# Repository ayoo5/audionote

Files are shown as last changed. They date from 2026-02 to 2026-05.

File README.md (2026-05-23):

<div align="center">
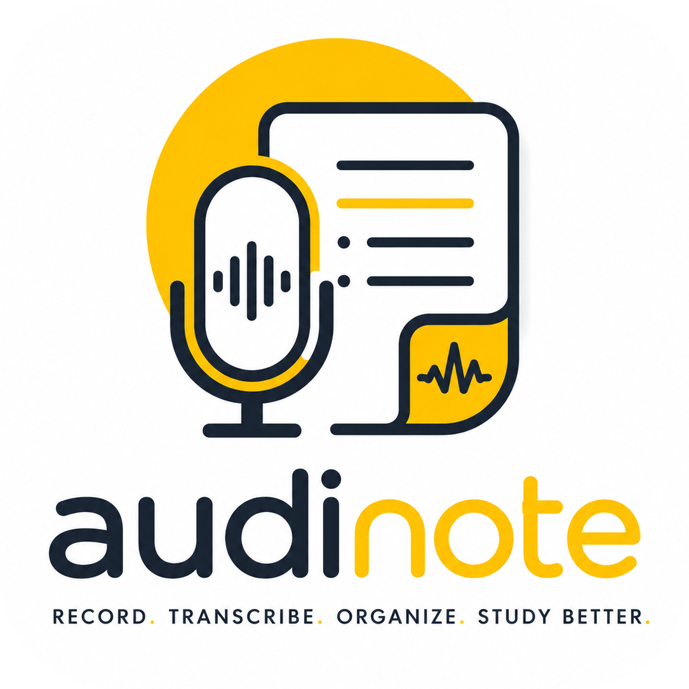
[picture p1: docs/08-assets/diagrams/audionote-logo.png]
Audionote Logo
  
  <br>
  <h3 style="margin-bottom: 0; line-height: 1;"><strong>Audionote</strong></h3>
  
  ESP32-powered asynchronous lecture transcription and archival system with automated cloud upload, cloud-based speech-to-text processing, and structured Google Shared Drive organization.
</div>

<div align="center">

| Initial Build Setup | Final Enclosed Build <br> (not the 3D printed enclosure) |
| :---: | :---: |
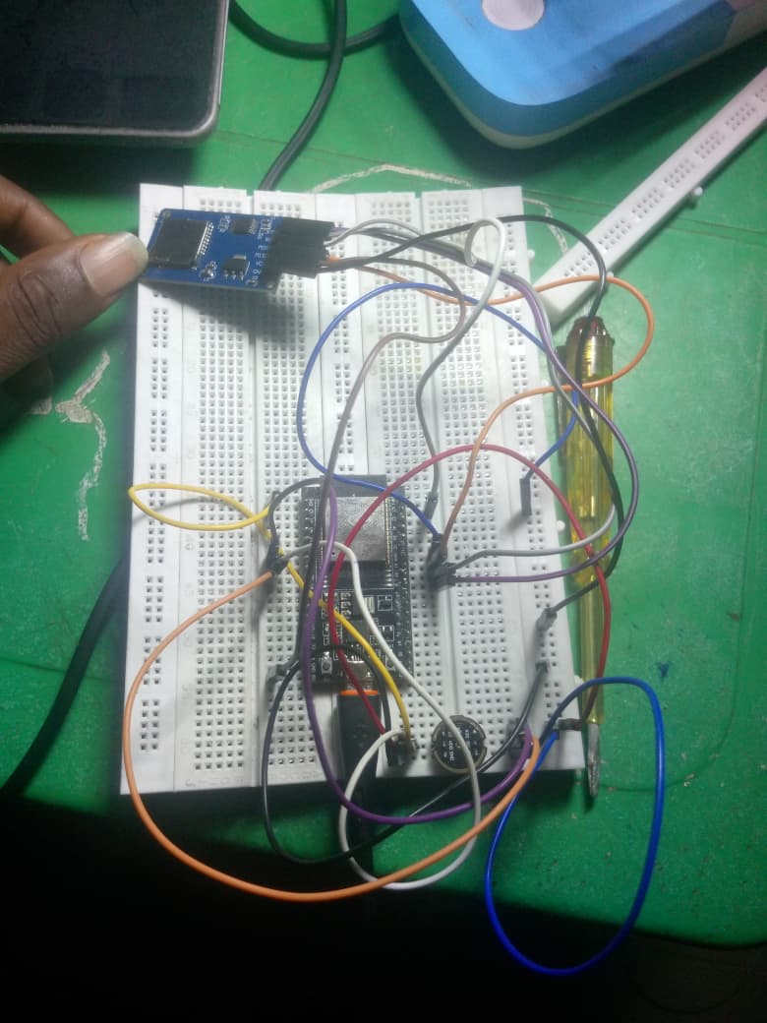
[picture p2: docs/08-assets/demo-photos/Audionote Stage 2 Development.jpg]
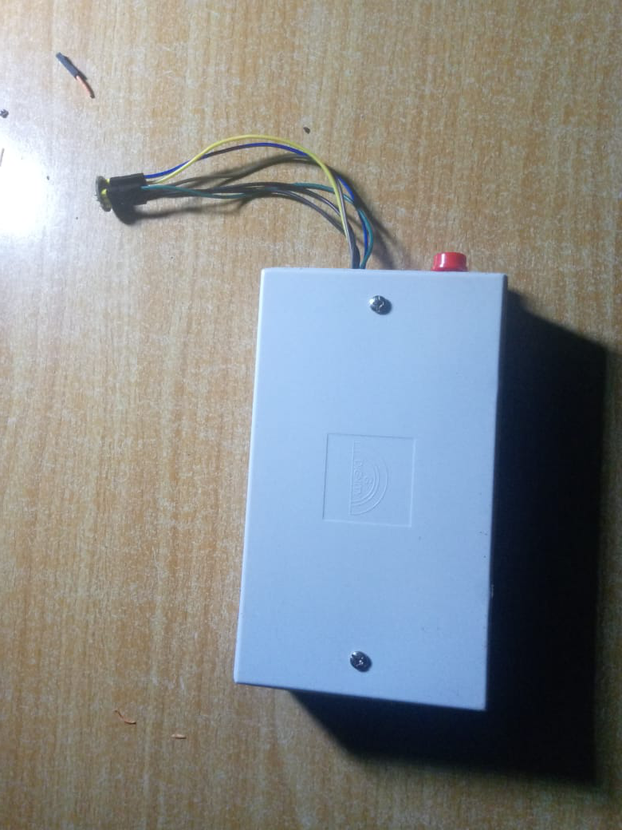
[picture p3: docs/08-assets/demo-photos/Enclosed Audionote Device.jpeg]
|  |  |

</div>

# Overview

Audionote is a low-cost embedded lecture transcription and archival platform designed for educational environments with unreliable connectivity and limited infrastructure.

The system captures lecture audio using an ESP32-based embedded device, stores recordings locally on an SD card, uploads audio recordings to a cloud backend in chunks once Wi-Fi becomes available, automatically transcribes the recordings using cloud speech-to-text services, and archives both the audio and transcript files in an organized Google Shared Drive structure.

The project was developed as part of the design and implementation of an asynchronous lecture transcription and archive device system for tertiary educational environments.

# Why Audionote Exists

Traditional note-taking methods are often incomplete, inconsistent, and inaccessible to many students.

In many developing educational environments, real-time transcription systems are impractical due to:

* unstable internet connectivity,
* high cloud streaming costs,
* limited embedded processing power,
* and infrastructure limitations.

Audionote addresses these constraints through an asynchronous edge-to-cloud architecture that prioritizes:

* reliable lecture capture,
* cloud-assisted transcription,
* structured archival,
* and educational accessibility.

The system is particularly useful for:

* students reviewing lecture content,
* accessibility support,
* institutional lecture archiving,
* asynchronous learning,
* and educational content preservation.

# Core Features

## Embedded Systems Features

* ESP32-based audio acquisition pipeline
* INMP441 I2S MEMS microphone integration
* WAV audio recording and formatting
* Local SD card audio buffering and storage
* Push-button lecture recording control
* Chunked upload architecture for large audio recordings
* Portable low-power embedded system design
* Recoverable upload workflow
* Hardware modularity for future PCB migration

## Cloud Features

* Secure signed upload URL generation
* Chunked cloud upload pipeline
* Google Cloud Run backend services
* Automated speech-to-text transcription
* Automatic Google Shared Drive organization
* Cloud-based lecture archival system
* Structured folder organization by course and level
* Cloud storage redundancy

## Systems Engineering Features

* Distributed edge-to-cloud architecture
* Asynchronous post-recording transcription
* Local-first fault-tolerant workflow
* Modular firmware and backend separation
* Recoverable upload session handling
* Automated backend processing pipeline
* Persistent local recording backup
* Scalable backend infrastructure

# System Architecture

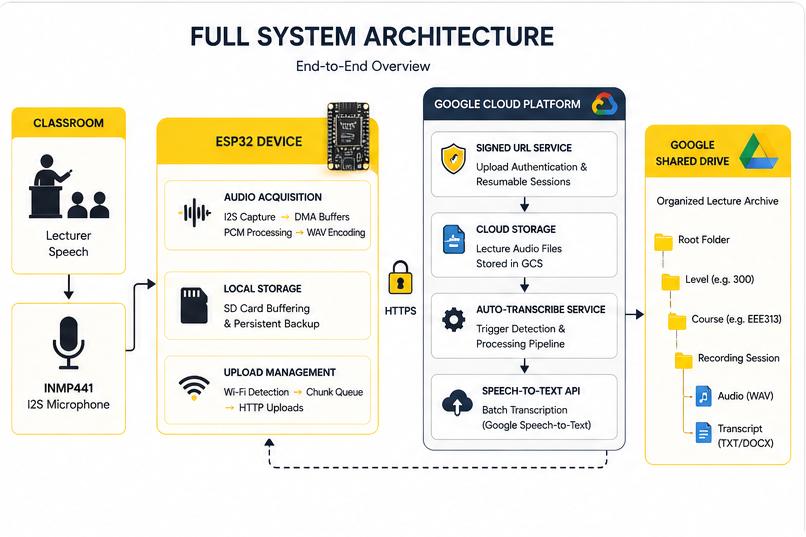
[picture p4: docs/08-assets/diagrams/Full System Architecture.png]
System architecture


## End-to-End Operational Workflow

```text
1. Lecturer powers the device
2. ESP32 initializes peripherals
3. Audio is captured from the INMP441 microphone
4. Audio is encoded into WAV format
5. Recording is stored locally on SD card
6. Recording session stops
7. Wi-Fi connection is detected
8. Audio file uploads in chunks to backend
9. Cloud backend processes uploaded recording
10. Speech-to-text transcription is generated
11. Audio and transcript are archived automatically
12. Files become accessible through Shared Drive
```

# Engineering Results Snapshot

Audionote was experimentally evaluated under realistic classroom and network conditions using an ESP32-based asynchronous lecture transcription architecture.

The system demonstrated stable operation across:
- extended recording sessions,
- cloud-based asynchronous transcription,
- structured archival workflows,
- and resumable upload recovery scenarios.

---

## Key Experimental Results

| Metric | Observation |
|---|---|
| Audio Sampling Rate | Stable 16 kHz PCM acquisition |
| Transcription Architecture | Asynchronous cloud-based pipeline |
| Average WER | ~35% under classroom conditions |
| Transcript Completeness | Typically 95–105% |
| Storage Efficiency | ~1.9–2.0 MB/min |
| Processing Throughput | Up to 2–5× real-time under favorable conditions |
| Button Reliability | >93% consistency across ~100 trials |
| File Organization | Structured timestamped archival successful |
| Upload Reliability | Improved using resumable uploads |
| System Stability | Stable extended operation observed |

---

## Key Engineering Observations

- Cloud-based ASR improved transcription quality compared to fully edge-based processing.
- Asynchronous transcription significantly reduced firmware complexity and memory pressure on the ESP32.
- Resumable uploads improved fault tolerance during unstable network conditions.
- Structured cloud archival improved retrieval and scalability.
- Signal integrity was strongly influenced by microphone cable length and solder quality.

---

## Notable System Trade-offs

| Design Choice | Trade-off |
|---|---|
| Cloud ASR | Better accuracy but network dependency |
| Asynchronous Processing | Better stability but no real-time feedback |
| ESP32-Based Design | Low-cost but resource constrained |
| Wearable Form Factor | Better audio capture but tighter hardware integration |

---

## Reference

Detailed experimental evaluation, metrics, formulas, and engineering analysis are documented in:

→ [Engineering Analysis](docs/06-analysis/engineering-analysis.md)

# Repository Structure

```text
lecture-transcription-iot/
│
├── firmware/          # ESP32 firmware source code
├── backend/           # Cloud backend services
├── hardware/          # Schematics, wiring, enclosure files
├── docs/              # Full technical documentation
├── media/             # Demo assets and presentation materials
└── README.md          # You are here 🙂
```

# Quick Start Roadmap

This project is organized as a guided end-to-end engineering workflow.

The recommended implementation path is:

```text
Firmware Environment Setup
        ↓
ESP32 Firmware Upload
        ↓
Hardware Component Acquisition
        ↓
Incremental Hardware Assembly & Testing
        ↓
Power System Integration
        ↓
Backend Deployment (Google Cloud)
        ↓
Shared Drive & Domain Setup
        ↓
Final System Integration
        ↓
Enclosure & Portability Upgrades
        ↓
Testing, Optimization & Contributions
```

The sections below guide you through each stage of the build process in the recommended engineering order.

## Stage 1 — Firmware Development Environment

The firmware is responsible for:

* audio acquisition,
* WAV formatting,
* SD card storage,
* chunked upload handling,
* Wi-Fi connectivity,
* and upload session management.

## Firmware Pipeline

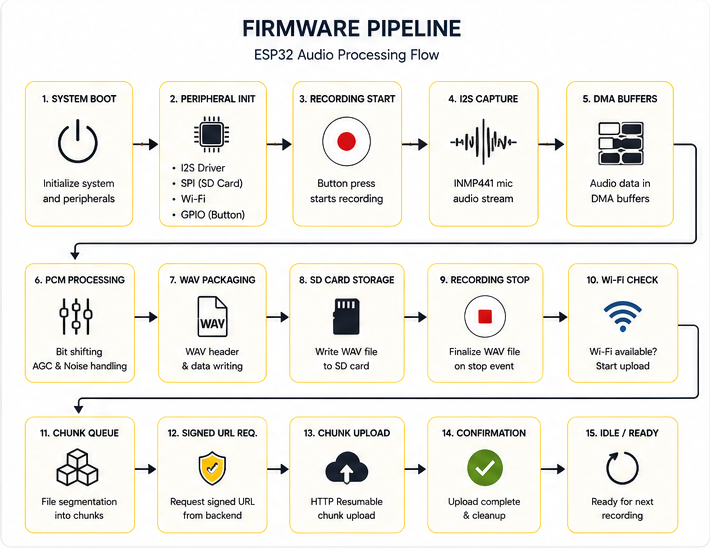
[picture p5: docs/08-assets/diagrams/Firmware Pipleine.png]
Firmware Pipeline


Before assembling the hardware, first prepare the ESP32 firmware environment and confirm that firmware can be successfully uploaded to the board.

This stage includes:

- Installing Arduino IDE
- Installing the ESP32 board package
- Installing required firmware libraries
- Configuring the firmware project
- Verifying serial communication
- Uploading firmware to the ESP32

Continue to:

→ [Firmware Overview](docs/03-firmware/firmware-overview.md)

And then:

→ [Firmware Setup](docs/03-firmware/esp32-setup.md)

## Stage 2 — Hardware Components & BOM

After validating the firmware environment, acquire the required hardware components and development materials.

This section includes:

- Main embedded components
- Power system components
- Wiring materials
- Development accessories
- Optional enclosure materials

Continue to:

→ [Bill of Materials](docs/02-hardware/bill-of-materials.md)

## Stage 3 — Hardware Assembly & Incremental Testing

The hardware integration process is intentionally broken into incremental validation stages to simplify debugging and subsystem verification.

### Hardware Block Diagram

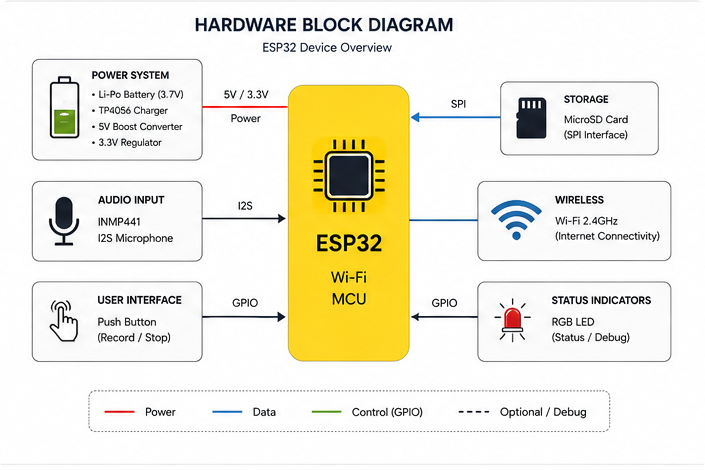
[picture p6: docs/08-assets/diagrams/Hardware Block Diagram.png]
Hardware Block Diagram


This stage includes:

- ESP32 basic validation
- INMP441 microphone integration
- SD card module integration
- Audio recording verification
- Chunk upload validation
- Hardware troubleshooting checkpoints

Continue to:

→ [Hardware Assembly Guide](docs/02-hardware/assembly-guide.md)

## Stage 4 — Power System Integration

After validating the core audio and upload system, integrate the portable power subsystem.

This stage includes:

- Battery integration
- TP4056 charging module setup
- MT3608 voltage regulation
- Power stability testing
- Brownout prevention
- Safe portable deployment

Continue to:

→ [Power System Documentation](docs/02-hardware/power-system.md)

## Stage 5 — Backend Infrastructure Setup

Deploy the Google Cloud backend services required for upload orchestration and transcription.

### Backend Pipeline

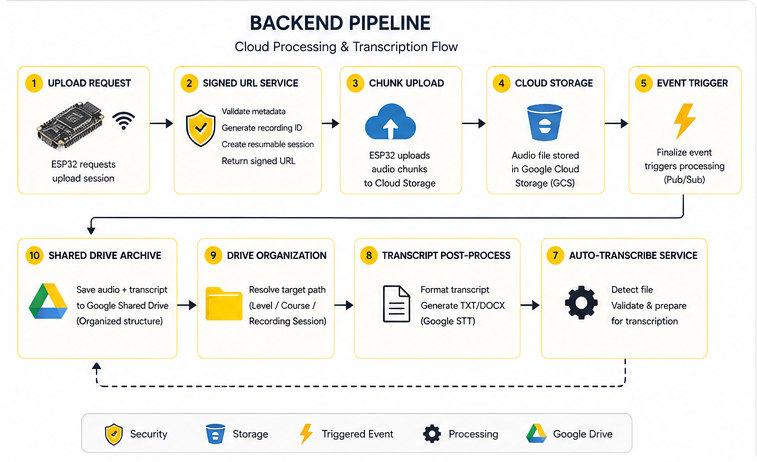
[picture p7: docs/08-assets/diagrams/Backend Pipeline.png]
Backend Pipeline


This stage includes:

- Google Cloud project setup
- Cloud Run deployment
- Signed URL service setup
- Auto-transcription service setup
- Storage bucket configuration
- IAM permissions configuration

Continue to:

→ [Backend Overview](docs/04-backend/backend-overview.md)

## Backend Deployment

Choose your preferred deployment workflow:

### Option 1 — GUI-Based Deployment (Recommended for Beginners)

Step-by-step Google Cloud Console deployment using mostly the graphical interface.

→ [GUI Backend Deployment Guide](docs/04-backend/deployment-gui-based.md)

---

### Option 2 — CLI-Based Deployment

Terminal-based deployment using gcloud and Cloud Shell.

→ [CLI Backend Deployment Guide](docs/04-backend/deployment-guide.md)

## Stage 6 — Shared Drive & Domain Configuration

Configure the shared archival environment for automated transcript organization.

This stage includes:

- Google Workspace setup
- Shared Drive creation
- Domain configuration
- Drive API integration
- Folder structure automation

Continue to:

→ [Shared Drive Setup Guide](docs/04-backend/shared-drive-integration.md)

## Stage 7 — Final Integration & Enclosure Assembly

Combine all validated subsystems into the final portable deployment configuration.

### Final Prototype

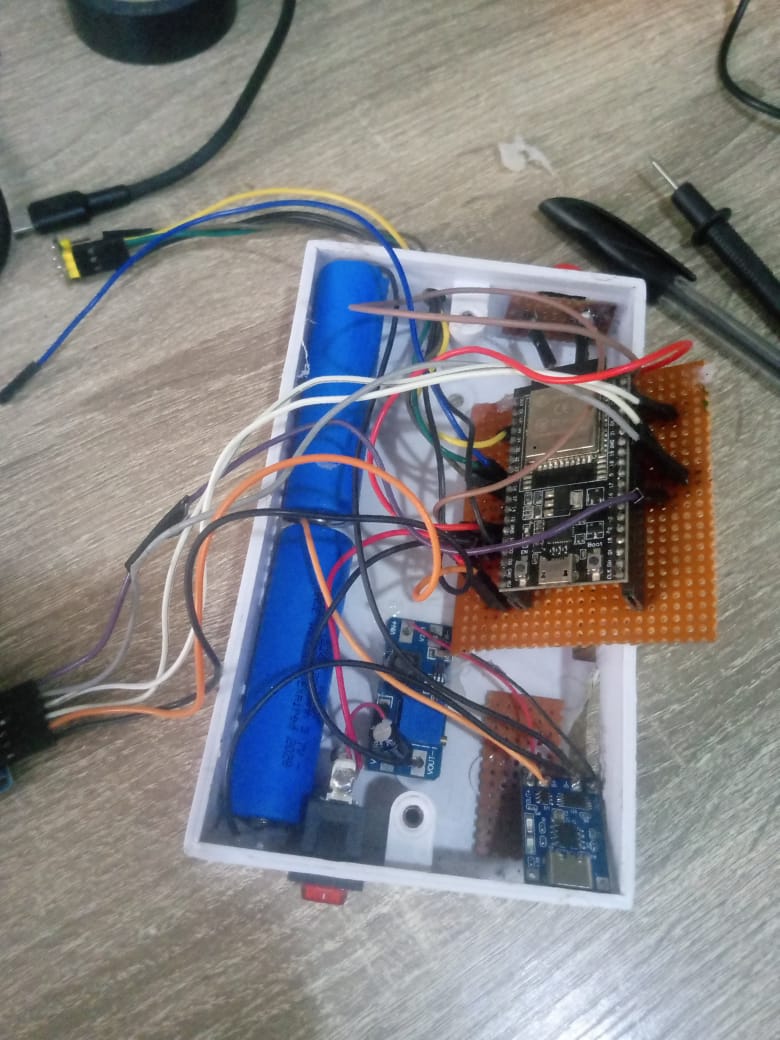
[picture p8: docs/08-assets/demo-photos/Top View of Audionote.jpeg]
Final Prototype


This stage includes:

- Internal component mounting
- Cable management
- [Enclosure assembly](/hardware/enclosure) designed by a friend, [Elias](https://github.com/buildwithelias)
- Thermal considerations
- Wearable mounting system integration
- Final operational testing

Continue to:

→ [Final System Integration](docs/05-system-integration/full-system-integration.md)

## Stage 8 — Optional Upgrades & Contributions

Audionote is designed as a modular and extensible embedded systems platform.

Optional enhancements include:

- 3D printed enclosure upgrades
- Alternative speech-to-text models
- OTA firmware updates
- Noise suppression pipelines
- Custom PCB development
- Mobile configuration systems

Contributors and builders are encouraged to:

- share their builds,
- submit pull requests,
- experiment with backend architectures,
- improve subsystem reliability,
- and extend the platform into new educational or embedded use cases.

Continue to:

→ [Contributing Guide](CONTRIBUTING.md)

## Stage 9 — Engineering Analysis & System Evaluation

This repository includes measured engineering analysis and implementation tradeoff documentation intended to support:

- reproducibility,
- system evaluation,
- embedded optimization,
- and academic engineering analysis.

Included analysis areas:

- memory usage measurements
- upload latency analysis
- storage utilization analysis
- chunk upload optimization
- backend processing latency
- power consumption measurements
- reliability observations
- embedded systems tradeoffs

These documents are especially useful for:

- embedded systems learners,
- engineering students,
- firmware developers,
- and contributors seeking to optimize or extend the system.

Continue to:

→ [Engineering Analysis](docs/06-analysis/build-analysis.md)

## Stage 10 — Troubleshooting & Debugging

Due to the multi-domain nature of the project (embedded systems, cloud infrastructure, storage systems, networking, and power electronics), troubleshooting documentation is provided throughout the repository.

Common troubleshooting areas include:

- ESP32 flashing failures
- SD card mounting issues
- I2S microphone configuration problems
- distorted or clipped audio
- Wi-Fi upload instability
- Cloud authentication failures
- Speech-to-text API errors
- power instability and brownouts
- backend deployment failures

The troubleshooting documentation also includes:

- incremental validation checkpoints,
- expected subsystem outputs,
- debugging methodology,
- and common failure recovery procedures.

---

# Contact & Project Updates

If you recreate, improve, or extend Audionote, feel free to share your build, feedback, or ideas.

I’d genuinely love to see:
- recreated builds,
- backend improvements,
- enclosure redesigns,
- PCB versions,
- and transcription experiments.

## Contact

- Email: krestonayo5@gmail.com
- LinkedIn: https://linkedin.com/in/chrisayo/
- GitHub: https://github.com/Ayoo5

## Sharing Your Build

If you share your recreation publicly, consider tagging:
- #AudionoteProject
- #ESP32
- #EmbeddedSystems
- my social media handles. (Just search "Christopher Ayomide Popoola" to find them.)

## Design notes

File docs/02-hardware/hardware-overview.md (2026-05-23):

# Hardware Overview

This document explains the physical architecture, subsystem design, and engineering considerations behind the Audionote hardware system.

Hardware Block Diagram

The hardware layer is responsible for:

* audio acquisition,
* local storage,
* portable power delivery,
* user interaction,
* and embedded system deployment.

The Audionote hardware architecture was designed to balance:

* affordability,
* portability,
* reproducibility,
* and practical engineering constraints.

---

# Hardware System Responsibilities

The hardware system performs several major functions:

| Subsystem | Purpose |
| --- | --- |
| Audio Capture System | Lecture recording |
| Embedded Processing System | Device control |
| Local Storage System | WAV file storage |
| Power Management System | Portable operation |
| User Input System | Recording control |
| Enclosure System | Mechanical protection |

---

# High-Level Hardware Architecture

```text id="n9lh6j"
Lecturer Audio
        ↓
INMP441 Microphone
        ↓
ESP32 Processing System
        ↓
MicroSD Storage
        ↓
Power Management System
        ↓
Cloud Upload Infrastructure
```

---

# Hardware Design Philosophy

The hardware architecture prioritizes:

| Goal | Reason |
| --- | --- |
| Low Cost | Accessibility |
| Modularity | Easier debugging |
| Portability | Real-world usability |
| Simplicity | Reproducibility |
| Cloud Integration | Scalability |

---

# Hardware Architecture Overview

The system combines:

* embedded processing,
* digital audio acquisition,
* removable storage,
* battery operation,
* and wireless networking.

---

# Core Hardware Components

| Component | Role |
| --- | --- |
| ESP32 DevKitC  | Main controller |
| INMP441 | Digital MEMS microphone |
| MicroSD Module | Audio storage |
| TP4056 | Battery charging |
| MT3608 | Voltage boosting |
| Li-ion Battery | Portable power |
| Push Button | Recording control |

---

# Main Processing System

The primary embedded controller used is:

```text id="sjvjlwm"
ESP32-WROOM-32D DevKitC
```

The ESP32 manages:

* audio sampling,
* file generation,
* SD card access,
* Wi-Fi communication,
* and upload orchestration.

---

# Why the ESP32 Was Selected

The ESP32 was selected because it provides:

* integrated Wi-Fi,
* native I2S support,
* strong embedded performance,
* and wide ecosystem support.

---

# ESP32 Advantages

| Feature | Benefit |
| --- | --- |
| Wi-Fi | Cloud uploads |
| I2S Peripheral | Digital microphone support |
| Dual-Core MCU | Better task handling |
| GPIO Availability | Peripheral integration |
| Low Cost | Accessibility |

---

# ESP32 Documentation

* [ESP32 Documentation](https://docs.espressif.com/projects/esp-idf/en/latest/esp32/?utm_source=chatgpt.com)

---

# Audio Capture System

Audionote uses:

* the INMP441 digital MEMS microphone

for lecture audio acquisition.

The microphone interfaces with the ESP32 using:

* the I2S digital audio protocol.

---

# Why the INMP441 Was Chosen

The INMP441 was selected because it:

* simplifies digital audio acquisition,
* improves signal quality,
* and integrates well with ESP32 I2S peripherals.

---

# Audio Capture Pipeline

```text id="iyqbjlwm"
Lecturer Speech
        ↓
INMP441 MEMS Microphone
        ↓
Digital I2S Audio Stream
        ↓
ESP32 Audio Buffer
        ↓
WAV File Generation
```

---

# INMP441 Documentation

* [INMP441 Datasheet](https://invensense.tdk.com/products/digital/inmp441/?utm_source=chatgpt.com)

---

# Storage System

The system uses:

* a MicroSD card module

for local WAV file storage.

This allows:

* offline recording,
* asynchronous uploads,
* and recording persistence.

---

# Storage Workflow

```text id="xjlwm1"
Audio Recording
        ↓
WAV File Generation
        ↓
MicroSD Storage
        ↓
Upload Queue
```

---

# Why Local Storage Was Important

Without local storage:

* network instability could interrupt recordings,
* upload failures could result in data loss,
* and the device would become less reliable.

Local storage improves:

* reliability,
* fault tolerance,
* and scalability.

---

# Power System Overview

Audionote was designed as a:

* portable battery-powered embedded device.

The power subsystem includes:

* rechargeable lithium-ion batteries,
* charging circuitry,
* voltage regulation,
* and power stabilization.

---

# Power Architecture

```text id="8q2jlwm"
Li-ion Battery
        ↓
TP4056 Charging Module
        ↓
MT3608 Boost Converter
        ↓
ESP32 + Peripheral Systems
```

---

# Why Battery Power Was Chosen

Battery operation enables:

* portability,
* wearable deployment,
* classroom flexibility,
* and independent operation.

---

# Power System Components

| Component | Purpose |
| --- | --- |
| Li-ion Battery | Portable energy source |
| TP4056 | Safe charging |
| MT3608 | Voltage boosting |
| Capacitor | Power stabilization |

---

# Power Stability Considerations

The ESP32 can experience:

* sudden current spikes,
* Wi-Fi transmission surges,
* and transient instability.

To improve stability:

* a 470uF capacitor was added across the power rails.

---

# Capacitor Placement

The capacitor should be connected:

* between VCC and GND,
* near the ESP32 power input.

This helps:

* reduce voltage dips,
* improve stability,
* and reduce unexpected resets.

---

# Recommended Capacitor Orientation

```text id="sjlwm2"
Capacitor (+) → VCC
Capacitor (-) → GND
```

---

# User Interaction System

A push button is used for:

* recording control,
* user interaction,
* and workflow management.

---

# Button Workflow

```text id="jlwm3r"
Button Press
        ↓
Recording Starts
        ↓
Button Press
        ↓
Recording Stops
```

---

# Mechanical Design Philosophy

The enclosure design prioritizes:

* portability,
* durability,
* accessibility,
* and iterative prototyping.

---

# Initial Prototype Enclosure

The initial prototype utilized:

* a double socket pattress enclosure.

This allowed:

* rapid prototyping,
* easier drilling,
* and faster iteration.

---

# Optional Final Enclosure

A dedicated:

* 3D printable enclosure

can also be used for:

* cleaner assembly,
* improved portability,
* and professional presentation.

---

# Enclosure Resources

→ [3D Models](/hardware/enclosure)

---

# Wearable Deployment Concept

The device can optionally integrate:

* Velcro straps,
* buckle systems,
* and soft material mounting solutions

for wearable lecture recording deployment.

---

# Example Deployment Concept

```text id="jlwm4p"
Lecturer Waist Strap
        ↓
Portable Recording Unit
        ↓
Wearable Lecture Capture
```

---

# Wiring & Signal Integrity Considerations

Signal quality can be affected by:

* long wire lengths,
* poor solder joints,
* loose grounds,
* and unstable power delivery.

---

# Recommended Hardware Practices

| Practice | Why It Helps |
| --- | --- |
| Short microphone wires | Better signal integrity |
| Proper solder joints | Reliability |
| Heat shrink insulation | Safety |
| Stable grounds | Reduced noise |
| Power rail decoupling  | Better stability |

---

# Hardware Validation Workflow

Recommended incremental validation strategy:

```text id="jlwm5q"
Validate Power Rails
        ↓
Validate ESP32 Boot
        ↓
Validate I2S Microphone
        ↓
Validate SD Card
        ↓
Validate Recording
        ↓
Validate Upload
```

This significantly simplifies debugging.

---

# Recommended Debugging Tools

| Tool | Purpose |
| --- | --- |
| Multimeter | Voltage verification |
| Arduino Serial Monitor | Firmware debugging |
| SD Card Reader | File inspection |
| USB Power Meter | Power analysis |

---

# Important Engineering Note

The hardware layer directly interfaces with:

* timing-sensitive audio systems,
* embedded storage systems,
* battery-powered circuitry,
* and wireless communication hardware.

Because of this:

* wiring quality,
* soldering consistency,
* power stability,
* and subsystem isolation

strongly influence overall system reliability.

---

# Hardware Engineering Trade-offs

| Design Choice | Trade-off |
| --- | --- |
| ESP32 Platform | Affordable but resource constrained |
| WAV Storage | Better STT quality but larger files |
| Battery Operation | Portable but power-sensitive |
| Modular Wiring | Easier debugging but bulkier assembly |

---

# Recommended Future Hardware Improvements

Potential future upgrades include:

| Upgrade | Purpose |
| --- | --- |
| Custom PCB | Cleaner integration |
| Better MEMS Microphones | Improved audio quality  |
| Battery Monitoring IC | Power analytics |
| Dedicated Audio Codec | Improved signal quality |
| Compact Enclosure | Better portability |

---

# Hardware Engineering Takeaways

The Audionote hardware architecture demonstrates practical integration between:

* embedded electronics,
* digital audio systems,
* portable power systems,
* and cloud-connected embedded workflows.

The system intentionally balances:

* affordability,
* engineering accessibility,
* modularity,
* and practical deployment constraints.

---

# Related Documentation

## Hardware Assembly Guide

→ [Hardware Assembly Guide](assembly-guide.md)

## Power System Guide

→ [Power System Guide](power-system.md)

## Firmware Overview

→ [Firmware Overview](../01-firmware/firmware-overview.md)

## Full System Integration Guide

→ [Full System Integration Guide](../05-system-integration/full-system-integration.md)

---

# Additional Resources

## ESP32 Documentation

* [ESP32 Documentation](https://docs.espressif.com/projects/esp-idf/en/latest/esp32/?utm_source=chatgpt.com)

## Arduino IDE Documentation

* [Arduino IDE Documentation](https://docs.arduino.cc/software/ide-v2?utm_source=chatgpt.com)

## INMP441 Datasheet

* [INMP441 Datasheet](https://invensense.tdk.com/products/digital/inmp441/?utm_source=chatgpt.com)

## TP4056 Reference

* [TP4056 Datasheet Reference](https://www.datasheet-pdf.info/entry/TP4056?utm_source=chatgpt.com)

## MT3608 Reference

* [MT3608 Reference Documentation](https://www.sunrom.com/download/327.pdf?utm_source=chatgpt.com)

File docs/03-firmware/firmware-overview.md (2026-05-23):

# Firmware Overview

This document explains the architecture, operational flow, and engineering decisions behind the Audionote firmware system.

Firmware Pipeline

The firmware is responsible for:

* audio acquisition,
* WAV file generation,
* SD card storage,
* wireless communication,
* upload orchestration,
* and cloud backend interaction.

The firmware acts as the embedded control layer that bridges:

* real-world audio capture,
* local embedded processing,
* and cloud-assisted transcription infrastructure.

---

# Firmware Responsibilities

The ESP32 firmware performs several major tasks:

| Responsibility | Purpose |
| --- | --- |
| Audio Sampling | Capture lecture audio |
| WAV File Generation  | Structured audio formatting |
| SD Card Storage | Persistent local storage |
| Push Button Handling | User interaction |
| Wi-Fi Management | Cloud connectivity |
| Upload Orchestration | Cloud transfer |
| Memory Management | Embedded stability |
| Status Logging | Debugging & monitoring |

---

# Firmware Architecture Overview

```text id="56q7qs"
Push Button Input
        ↓
Recording Controller
        ↓
INMP441 Audio Capture
        ↓
I2S Audio Processing
        ↓
WAV File Generation
        ↓
MicroSD Storage
        ↓
Wi-Fi Detection
        ↓
Chunked Upload System
        ↓
Cloud Backend
```

---

# Why the ESP32 Was Chosen

The ESP32 was selected because it provides:

* integrated Wi-Fi,
* I2S support,
* sufficient embedded performance,
* low cost,
* and strong developer ecosystem support.

---

# Advantages of the ESP32

| Feature | Benefit |
| --- | --- |
| Built-in Wi-Fi | Cloud uploads |
| I2S Peripheral | Digital microphone support |
| Dual-core MCU | Task flexibility |
| Low Cost | Accessibility |
| Large Community Support | Easier development |

---

# ESP32 Variant Used

The primary development platform used was:

```text id="6apvks"
ESP32-WROOM-32D DevKitC
```

---

# ESP32 Documentation

* [ESP32 Documentation](https://docs.espressif.com/projects/esp-idf/en/latest/esp32/?utm_source=chatgpt.com)

---

# Audio Acquisition System

Audionote uses the:

* INMP441 digital MEMS microphone

for lecture audio acquisition.

The microphone communicates with the ESP32 using:

* the I2S protocol.

---

# Why I2S Was Used

I2S was selected because it:

* simplifies digital audio acquisition,
* improves signal integrity,
* and avoids analog microphone noise issues.

---

# Audio Pipeline

```text id="h1h8az"
Lecturer Audio
        ↓
INMP441 Microphone
        ↓
I2S Audio Stream
        ↓
ESP32 Audio Buffer
        ↓
WAV File Generation
```

---

# INMP441 Documentation

* [INMP441 Datasheet](https://invensense.tdk.com/products/digital/inmp441/?utm_source=chatgpt.com)

---

# WAV File Generation

The firmware converts raw I2S audio data into:

* structured WAV audio files.

This allows:

* compatibility with transcription services,
* easier debugging,
* and standard audio processing workflows.

---

# Why WAV Format Was Chosen

| Reason | Benefit |
| --- | --- |
| Standardized format | Wide compatibility |
| Lossless audio | Better transcription quality |
| Easy debugging | Inspectable recordings |
| STT compatibility | Cloud integration |

---

# Storage Architecture

Audio recordings are stored locally using:

* a MicroSD card module.

This enables:

* offline recording,
* upload retries,
* and recording persistence.

---

# Storage Workflow

```text id="4cfbx4"
Audio Capture
        ↓
WAV Generation
        ↓
Local SD Storage
        ↓
Upload Queue
```

---

# Why Local Storage Was Important

Without local storage:

* unstable Wi-Fi could interrupt recordings,
* uploads could fail permanently,
* and reliability would decrease significantly.

Local storage improves:

* fault tolerance,
* reliability,
* and asynchronous operation.

---

# Upload Architecture

Audionote uses:

* delayed asynchronous uploads.

Recordings are uploaded:

* after recording stops,
* and after Wi-Fi becomes available.

---

# Upload Workflow

```text id="yo8gb4"
Recording Stops
        ↓
Wi-Fi Detected
        ↓
Signed URL Requested
        ↓
Chunked Upload Begins
        ↓
Cloud Storage Upload
```

---

# Why Asynchronous Uploading Was Chosen

Streaming audio directly from the ESP32 introduces:

* memory pressure,
* network instability,
* synchronization complexity,
* and increased failure probability.

Asynchronous uploads improve:

* stability,
* reliability,
* and embedded simplicity.

---

# Chunked Uploading

The firmware uploads recordings in chunks to improve:

* upload stability,
* recovery behavior,
* and memory efficiency.

---

# Benefits of Chunked Uploading

| Benefit | Explanation |
| --- | --- |
| Lower RAM usage | Better ESP32 stability |
| Improved recovery | Retry failed chunks |
| Better scalability | Supports larger recordings |
| Reduced upload failure risk | More robust networking |

---

# Firmware State Flow

```text id="fxmjlwm"
Idle State
    ↓
Recording State
    ↓
Local Storage State
    ↓
Wi-Fi Detection State
    ↓
Upload State
    ↓
Backend Processing State
```

---

# Push Button Control System

The firmware uses a physical push button for:

* recording start,
* recording stop,
* and interaction control.

---

# Button Workflow

```text id="kkq9gi"
Button Press
        ↓
Recording Starts
        ↓
Button Press
        ↓
Recording Stops
```

---

# Debouncing Considerations

Mechanical push buttons can generate:

* noisy transitions,
* repeated triggers,
* and unstable readings.

The firmware includes debouncing logic to improve:

* reliability,
* user interaction consistency,
* and recording control stability.

---

# Wi-Fi Management

The ESP32 firmware continuously evaluates:

* network availability,
* upload readiness,
* and connection state.

---

# Why Wi-Fi Detection Matters

Uploads are only attempted when:

* recording is complete,
* and stable Wi-Fi is available.

This reduces:

* failed uploads,
* power waste,
* and unstable backend behavior.

---

# Firmware Logging & Debugging

The firmware outputs serial logs for:

* initialization monitoring,
* SD card validation,
* upload debugging,
* and runtime analysis.

---

# Recommended Debugging Tool

Arduino Serial Monitor:

* [Arduino IDE Documentation](https://docs.arduino.cc/software/ide-v2?utm_source=chatgpt.com)

---

# Typical Serial Logs

```text id="lx4v5g"
SD Card Mounted
Wi-Fi Connected
Recording Started
Upload Initialized
Upload Successful
```

---

# Memory Considerations

Embedded memory management was a major consideration during development.

The ESP32 has limited:

* RAM,
* buffer capacity,
* and filesystem resources.

---

# Firmware Design Decisions Influenced by RAM Constraints

| Design Choice | Reason |
| --- | --- |
| Chunked uploads | Reduce memory pressure |
| Post-processing transcription | Simpler embedded workflow |
| SD buffering | Avoid RAM overflow |
| Delayed uploads | Improve stability |

---

# Firmware Engineering Trade-offs

| Design Choice | Trade-off |
| --- | --- |
| WAV Storage | Larger files but better STT quality |
| Cloud STT | Better accuracy but internet dependency |
| ESP32 Platform | Affordable but resource constrained |
| Asynchronous Uploads | Stable but not real-time |

---

# Firmware Validation Strategy

The firmware was validated incrementally.

Recommended workflow:

```text id="2u0tk4"
Validate Boot
        ↓
Validate I2S Audio
        ↓
Validate WAV Generation
        ↓
Validate SD Storage
        ↓
Validate Wi-Fi
        ↓
Validate Upload
```

This significantly simplifies debugging.

---

# Important Engineering Note

The firmware layer is one of the most critical parts of the Audionote system because it directly interfaces with:

* physical hardware,
* timing-sensitive audio acquisition,
* filesystem operations,
* and asynchronous cloud communication.

Because of this:

* debugging,
* iterative testing,
* and gradual subsystem validation

are expected parts of development.

---

# Recommended Future Firmware Improvements

Potential future firmware upgrades include:

| Upgrade | Purpose |
| --- | --- |
| OTA Updates | Remote firmware upgrades  |
| Audio Compression | Smaller uploads |
| Real-Time Streaming STT | Live transcription |
| Battery Monitoring | Improved power management |
| Deep Sleep Modes | Lower power consumption |
| RTOS Task Optimization  | Better concurrency |

---

# Firmware Engineering Takeaways

The Audionote firmware demonstrates practical integration between:

* embedded audio acquisition,
* local storage systems,
* wireless networking,
* and cloud-connected workflows.

The system intentionally balances:

* embedded limitations,
* cloud scalability,
* reliability,
* and engineering accessibility.

---

# Related Documentation

## Firmware Setup Guide

→ [Firmware Setup Guide](esp32-setup.md)

## Hardware Assembly Guide

→ [Hardware Assembly Guide](../02-hardware/assembly-guide.md)

## Backend Overview

→ [Backend Overview](../04-backend/backend-overview.md)

## Full System Integration

→ [Full System Integration Guide](../05-system-integration/full-system-integration.md)

---

# Additional Resources

## ESP32 Documentation

* [ESP32 Documentation](https://docs.espressif.com/projects/esp-idf/en/latest/esp32/?utm_source=chatgpt.com)

## Arduino IDE Documentation

* [Arduino IDE Documentation](https://docs.arduino.cc/software/ide-v2?utm_source=chatgpt.com)

## INMP441 Datasheet

* [INMP441 Datasheet](https://invensense.tdk.com/products/digital/inmp441/?utm_source=chatgpt.com)

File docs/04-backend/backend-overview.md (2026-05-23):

# Backend Overview

This document explains the architecture, design philosophy, and operational flow of the Audionote backend infrastructure.

Backend Pipeline

The backend system is responsible for:

* securely receiving uploaded lecture recordings,
* processing transcription requests,
* organizing generated outputs,
* and integrating with Google Shared Drive for archival and accessibility.

Unlike traditional IoT systems that process data locally, Audionote utilizes a cloud-assisted backend architecture to overcome the computational and memory limitations of embedded hardware platforms such as the ESP32.

---

# Why the Backend Exists

The ESP32 is excellent for:

* audio acquisition,
* local storage,
* wireless communication,
* and embedded control.

However, advanced speech recognition workloads require:

* high compute capability,
* scalable processing,
* cloud APIs,
* and persistent storage infrastructure.

The backend bridges this gap by enabling:

* scalable transcription,
* centralized organization,
* remote accessibility,
* and automated processing workflows.

---

# Backend Responsibilities

The Audionote backend performs several major functions:

| Function | Purpose |
| --- | --- |
| Signed URL Generation | Secure upload authorization |
| Cloud Storage Management | Lecture audio storage |
| Automatic Transcription  | Speech-to-text processing |
| File Organization | Structured archival |
| Shared Drive Integration | Multi-user accessibility |
| Trigger Automation | Event-driven processing |
| Logging & Monitoring | Debugging and observability |

---

# High-Level Backend Architecture

```text id="x2mhyt"
ESP32 Device
        ↓
Signed URL Backend
        ↓
Google Cloud Storage
        ↓
Storage Trigger
        ↓
Auto-Transcription Backend
        ↓
Google Speech-to-Text
        ↓
Transcript Processing
        ↓
Google Shared Drive
```

---

# Why Signed URLs Were Used

Audionote uses signed URLs instead of directly exposing storage buckets to the ESP32.

This approach improves:

* security,
* scalability,
* access control,
* and backend flexibility.

---

# Signed URL Workflow

```text id="tzqv7u"
ESP32 Requests Upload Permission
                ↓
Backend Generates Temporary Signed URL
                ↓
ESP32 Uploads WAV File Securely
                ↓
Upload Permission Expires Automatically
```

---

# Advantages of Signed URLs

| Advantage | Benefit |
| --- | --- |
| Temporary Access | Improved security |
| No Direct Bucket Exposure | Reduced attack surface |
| Controlled Uploads | Better backend management |
| Scalable Architecture | Easier future expansion |

---

# Backend Services

The backend currently consists of two primary services.

---

# 1. Signed URL Service

Directory:

```text id="9m2m9g"
backend/signedurl
```

This service:

* receives upload initialization requests,
* authenticates requests,
* generates temporary upload URLs,
* and prepares cloud storage upload sessions.

---

# Responsibilities

| Responsibility | Purpose |
| --- | --- |
| Generate signed URLs | Secure uploads |
| Validate requests | Upload control |
| Configure upload targets | Storage organization |

---

# Typical Flow

```text id="0r5m73"
ESP32 Stops Recording
        ↓
ESP32 Detects Wi-Fi
        ↓
ESP32 Requests Upload URL
        ↓
Backend Returns Signed URL
        ↓
ESP32 Uploads Recording
```

---

# 2. Auto-Transcription Service

Directory:

```text id="gtx69j"
backend/autotranscribe
```

This service:

* monitors uploaded recordings,
* triggers transcription processing,
* processes transcript outputs,
* and organizes generated files.

---

# Responsibilities

| Responsibility | Purpose |
| --- | --- |
| Detect uploaded files | Event automation |
| Invoke Speech-to-Text | Transcript generation |
| Process transcript outputs | Organization |
| Integrate with Drive | Accessibility |

---

# Transcription Workflow

```text id="udx6j0"
WAV File Uploaded
        ↓
Storage Trigger Activates
        ↓
Auto-Transcription Backend Executes
        ↓
Google Speech-to-Text Processes Audio
        ↓
Transcript Generated
        ↓
Transcript Organized & Stored
```

---

# Why Post-Recording Batch Transcription Was Chosen

Audionote currently uses:

* post-recording batch transcription

instead of:

* live streaming transcription.

---

# Engineering Reasons

| Reason | Benefit |
| --- | --- |
| Reduced ESP32 Complexity | Simpler firmware |
| Lower Power Consumption  | Better portability |
| Improved Reliability | Fewer streaming failures |
| Better Upload Recovery | Retry capability |
| Reduced Memory Pressure  | Better ESP32 stability |

---

# Current Recording Flow

```text id="tlyc9r"
Lecture Recording
        ↓
Local WAV Storage
        ↓
Recording Stops
        ↓
Wi-Fi Detected
        ↓
Chunked Upload Begins
        ↓
Backend Processing
```

---

# Why Chunked Uploading Was Used

The system uploads recordings in chunks after recording stops and Wi-Fi becomes available.

This improves:

* upload stability,
* fault tolerance,
* large file handling,
* and embedded reliability.

---

# Benefits of Chunked Uploading

| Benefit | Explanation |
| --- | --- |
| Lower RAM usage | Important for ESP32 |
| Better recovery | Failed chunks can retry |
| Improved stability | Safer uploads |
| Easier scalability | Supports larger recordings |

---

# Cloud Storage Architecture

Audionote uses Google Cloud Storage for:

* lecture audio storage,
* transcription pipeline integration,
* and backend automation.

---

# Recommended Bucket Structure

```text id="49d5pq"
audionote-recordings/
        └── lectures/
              └── level/
                    └── course/
                          └── session/
```

---

# Event-Driven Backend Processing

Audionote uses event-driven backend execution.

This means:

* services execute automatically in response to upload events.

---

# Event Workflow

```text id="x0wotc"
File Uploaded to Bucket
        ↓
Cloud Storage Event Generated
        ↓
Trigger Activates
        ↓
Backend Executes Automatically
```

---

# Advantages of Event-Driven Architecture

| Advantage | Benefit |
| --- | --- |
| Reduced idle compute | Lower costs |
| Automatic scaling | Better reliability |
| Efficient processing | Faster workflows |
| Cloud-native architecture | Easier maintenance |

---

# Google Shared Drive Integration

Generated outputs can be automatically organized into:

* shared folders,
* course folders,
* lecture directories,
* and archival structures.

This improves:

* collaboration,
* accessibility,
* and academic organization.

---

# Shared Drive Example Structure

```text id="x0bdj4"
Shared Drive
    └── Department
          └── Course
                └── Lecture Session
                      ├── Audio Recording
                      ├── Transcript
                      └── Metadata
```

---

# Why Google Shared Drive Was Chosen

| Reason | Benefit |
| --- | --- |
| Multi-user access | Shared academic workflows |
| Large storage support | Lecture archival |
| Familiar ecosystem | Easy adoption |
| Cloud accessibility | Remote access |

---

# Backend Technologies Used

| Technology | Purpose |
| --- | --- |
| Google Cloud Run | Backend hosting |
| Google Cloud Storage  | File storage |
| Google Speech-to-Text | Transcription |
| Eventarc | Trigger automation |
| Google Drive API | Shared Drive integration |
| Node.js | Backend runtime |

---

# Why Cloud Run Was Chosen

Cloud Run was selected because it:

* scales automatically,
* supports containerized workloads,
* simplifies deployment,
* and integrates well with event-driven architectures.

---

# Cloud Run Advantages

| Advantage | Benefit |
| --- | --- |
| Automatic scaling | Efficient resource usage |
| Managed infrastructure | Reduced DevOps overhead |
| Easy deployment | Faster iteration |
| Event integration | Simplified backend automation |

---

# Important Engineering Note

The backend integration stage is typically the most technically demanding part of the Audionote system.

This stage combines:

* embedded firmware,
* cloud infrastructure,
* event automation,
* asynchronous uploads,
* authentication systems,
* and distributed backend services.

Because of this, debugging is an expected part of development.

---

# Recommended Development Approach

```text id="rk1k1m"
Validate Firmware
        ↓
Validate Upload
        ↓
Validate Storage
        ↓
Validate Trigger
        ↓
Validate Transcription
        ↓
Validate Shared Drive Integration
```

Incremental validation significantly simplifies debugging.

---

# Backend Logging & Monitoring

Cloud logs are extremely important for backend debugging.

Useful command:

```bash id="0iy8v7"
gcloud functions logs read autoTranscribeOnUpload --gen2 --region=europe-west1
```

This helps diagnose:

* trigger failures,
* backend crashes,
* permission problems,
* and deployment issues.

---

# Cloud Logging Console

* [Google Cloud Logging Console](https://console.cloud.google.com/logs?utm_source=chatgpt.com)

Useful for:

* real-time monitoring,
* debugging deployment issues,
* and backend observability.

---

# Using AI Assistance in Cloud Shell Editor

Google Cloud Shell Editor includes built-in AI assistance.

Shortcut:

```text id="7y2n5x"
Alt + G
```

This can help:

* interpret deployment errors,
* explain logs,
* troubleshoot Node.js issues,
* and debug Cloud Run deployments.

---

# Recommended Future Backend Improvements

Potential future upgrades include:

| Upgrade | Purpose |
| --- | --- |
| Improved transcription  | Integrating more advamced STT models |
| OTA firmware updates | Remote device maintenance |
| Local inference models  | Reduced cloud dependence  |
| Speaker diarization | Multi-speaker separation  |
| Summarization pipelines | Lecture condensation |
| Search indexing | Transcript searchability  |

---

# Backend Engineering Takeaways

The Audionote backend demonstrates practical integration between:

* embedded systems,
* cloud infrastructure,
* asynchronous processing,
* and event-driven architectures.

This project intentionally balances:

* embedded resource limitations,
* cloud scalability,
* system reliability,
* and engineering accessibility.

---

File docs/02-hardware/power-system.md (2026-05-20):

# Power System Guide

This section documents the portable power architecture used in the Audionote embedded lecture transcription system.

The objective of this stage is to safely integrate:

* the lithium battery system,
* charging circuitry,
* voltage regulation,
* and power distribution,

while ensuring stable ESP32 operation during:

* audio recording,
* SD card access,
* Wi-Fi transmission,
* and backend upload operations.m 

At the end of this section, you should have:

* a portable battery-powered Audionote device,
* stable regulated voltage rails,
* safe charging capability,
* and a validated power delivery system ready for enclosure integration.

---

# Power System Architecture

```text id="ytm9dy"
18650 Battery Cells
        ↓
Parallel Battery Pack
        ↓
TP4056 Charging Module
        ↓
MT3608 Boost Converter
        ↓
ESP32 + Peripheral Power Rail
        ↓
INMP441 + SD Module + Upload System
```

---

# Power System Objectives

The power subsystem must:

* provide stable voltage to the ESP32,
* support Wi-Fi current spikes,
* maintain SD card stability,
* prevent brownouts,
* support portable operation,
* and safely recharge the battery system.

---

# Before You Begin

Ensure the following stages are already completed:

* Firmware setup
* Hardware assembly
* Audio recording validation
* SD card validation
* Upload system validation

Continue from:

→ [Hardware Assembly Guide](assembly-guide.md)

---

# Required Power Components

| Component | Purpose |
| --- | --- |
| 18650 Li-Ion Cells | Main portable power source |
| TP4056 Module | Battery charging and protection |
| 470uF Capacitor | Voltage stabilizer, transient buffer|
| MT3608 Boost Converter | Voltage step-up regulation |
| Power Switch | Main system power control |
| Hook-up Wires | Power distribution |
| Heat Shrink Tubing | Electrical insulation |
| Multimeter | Voltage validation |
| Soldering Tools | Permanent connections |

---

# Important Safety Notes

Lithium battery systems must be handled carefully.

Before proceeding:

* Never short battery terminals
* Never puncture Li-Ion cells
* Do not charge damaged batteries
* Never connect LiPo batteries directly to the ESP32 3.3V rail
* Double-check polarity before powering the ESP32
* Always validate voltage outputs before connecting peripherals
* Insulate exposed terminals properly
* Disconnect batteries during wiring modifications
* Avoid powering the ESP32 from multiple unstable sources simultaneously

If you are unfamiliar with lithium battery handling:

* [Lithium-Ion Battery Safety Basics](https://batteryuniversity.com/article/bu-304a-safety-concerns-with-li-ion?utm_source=chatgpt.com)

---

# Power System Overview

Audionote uses:

* parallel 18650 lithium battery cells,
* a TP4056 charging/protection module,
* and an MT3608 boost converter

to create a rechargeable portable embedded power platform.

---

## Recommended Wiring Diagram

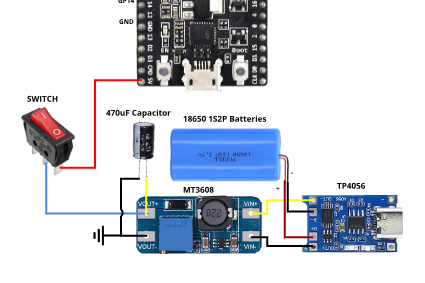
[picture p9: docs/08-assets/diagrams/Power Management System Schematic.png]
Power Management System Schematic


---

# Why Parallel Battery Configuration?

The batteries are connected in parallel primarily to:

* increase available current capacity,
* improve runtime,
* reduce voltage sag during Wi-Fi transmission,
* and improve overall system stability.

The system still operates at approximately:

```text id="6vysal"
3.7V nominal
```

while increasing battery capacity.

---

# Stage 1 — Battery Pack Assembly

## Recommended Battery Configuration

```text id="2k0xqx"
Battery (+) → Battery (+)
Battery (-) → Battery (-)
```

This creates a parallel battery pack.

---

# Important Parallel Battery Notes

Before connecting cells in parallel:

* Ensure both cells are at similar voltages
* Use identical battery types where possible
* Avoid mixing damaged or aged cells
* Insulate exposed terminals properly

---

# Validation Checkpoint

Using a multimeter:

| Test | Expected Result |
| --- | --- |
| Battery pack voltage  | ~3.7V to 4.2V |
| No excessive heating  | Stable |
| Stable voltage output | Stable |

---

# Stage 2 — TP4056 Charging Module Integration

The TP4056 module provides:

* battery charging,
* overcharge protection,
* over-discharge protection,
* and short-circuit protection.

---

# TP4056 Wiring

| TP4056 Pin | Connection |
| --- | --- |
| B+ | Battery Positive |
| B- | Battery Negative |
| OUT+ | Boost Converter Input + |
| OUT- | Boost Converter Input - |

---

# Important TP4056 Notes

Recommended:

* use the protected TP4056 version,
* ensure proper polarity,
* avoid loose battery connections.

TP4056 documentation and reference:

* [TP4056 Reference Documentation](https://www.datasheet-pdf.info/4226?utm_source=chatgpt.com)

---

# Charging Validation

Connect USB power to the TP4056.

Expected behavior:

| LED Indicator  | Meaning |
| --- | --- |
| Red LED | Charging |
| Blue/Green LED | Fully charged |

---

# Validation Checkpoint

| Test | Expected Result |
| --- | --- |
| Charging LED activates | Successful |
| Battery voltage increases | Successful |
| No overheating | Stable |

---

# Stage 3 — MT3608 Boost Converter Setup

The ESP32 and some peripherals require a stable regulated voltage source.

The MT3608 is used to boost the battery voltage to the required operating voltage.

---

# Important Warning

DO NOT connect the boost converter to the ESP32 before adjusting the output voltage.

Improper voltage may permanently damage the ESP32.

---

# MT3608 Wiring

| MT3608 Pin | Connection |
| --- | --- |
| IN+ | TP4056 OUT+ |
| IN- | TP4056 OUT- |
| OUT+ | ESP32 5V Pin  |
| OUT- | Common Ground |

---

# Adjusting the Output Voltage

Before connecting the ESP32:

1. Power the MT3608
2. Use a multimeter
3. Rotate the adjustment potentiometer slowly
4. Set output voltage carefully

Recommended output:

```text id="mjw9j7"
5.0V
```

---

# Validation Checkpoint

| Test | Expected Result |
| --- | --- |
| Output voltage | ~5.0V |
| Voltage stability | Stable |
| No overheating | Stable |

---

# Stage 3.5 — Power Rail Stabilization Capacitor

To improve system stability during:

- Wi-Fi transmission,
- SD card writes,
- boot current spikes,
- and upload operations,

a bulk electrolytic capacitor is recommended across the regulated ESP32 power rail.

---

# Recommended Capacitor

| Component | Recommended Value |
|---|---|
| Electrolytic Capacitor | 470µF |
| Voltage Rating | ≥ 10V |

---

# Recommended Placement

Connect the capacitor across:

```text
ESP32 5V ↔ GND
```

or equivalently:

```text
MT3608 OUT+ ↔ MT3608 OUT-
```

---

# Wiring Diagram

```text
MT3608 OUT+  ───────┬──────────→ ESP32 5V
                    │
                 470µF
               Capacitor
                    │
MT3608 OUT-  ───────┴──────────→ ESP32 GND
```

---

# Important Polarity Warning

Electrolytic capacitors are polarized.

Ensure:

| Capacitor Leg | Connection |
|---|---|
| Positive (+) | 5V Rail |
| Negative (-) | GND |

Incorrect polarity may damage the capacitor.

---

# Why This Capacitor Helps

The capacitor helps:

- reduce transient voltage drops,
- improve ESP32 stability,
- reduce brownouts,
- stabilize SD card writes,
- and improve Wi-Fi reliability.

This is especially useful in portable battery-powered ESP32 systems.

---

# Validation Checkpoint

After capacitor installation:

| Test | Expected Result |
|---|---|
| ESP32 boot stability | Improved |
| Wi-Fi upload stability | Improved |
| Reduced random resets | Improved |
| SD reliability | Improved |

---

# Stage 4 — Power Switch Integration

A physical power switch is strongly recommended.

This allows:

* safe shutdown,
* battery isolation,
* and portable usability.

---

# Recommended Placement

Place the switch:

```text id="i6u8qn"
Between TP4056 OUT+ and MT3608 IN+
```

This isolates downstream power consumption.

---

# Validation Checkpoint

| Test | Expected Result |
| --- | --- |
| Switch powers system on/off | Successful |
| No intermittent power loss  | Stable |

---

# Stage 5 — ESP32 Power Validation

After validating regulated voltage:

1. Connect the MT3608 output to the ESP32 5V pin
2. Power on the system
3. Observe serial monitor

Expected output:

```text id="g4b8yk"
System Boot Successful
WiFi Initialized
SD Mounted
System Ready
```

---

# Important ESP32 Power Notes

The ESP32 may draw significant current during:

* Wi-Fi transmission,
* SD writes,
* and boot initialization.

Weak power systems may cause:

* brownouts,
* unexpected resets,
* or SD corruption.

---

# Brownout Testing

Observe the system during:

* Wi-Fi uploads,
* long recordings,
* and repeated recording cycles.

Watch for:

| Symptom | Possible Cause |
| --- | --- |
| Unexpected reboot | Voltage drop |
| SD corruption | Power instability  |
| Upload failure | Current starvation |
| Boot loops | Weak battery |

---

# Recommended Stability Improvements

If instability occurs:

* shorten power wiring,
* improve solder joints,
* increase battery capacity,
* improve grounding,
* or add bulk capacitance near the ESP32.

Optional improvement:

```text id="c4u1zk"
470µF capacitor across ESP32 power rails
```

This may help reduce transient voltage drops.

---

# Power System Validation Checklist

| Validation Item | Expected Result |
| --- | --- |
| Battery charging works | Successful |
| Boost converter stable | Successful |
| ESP32 boots reliably | Stable |
| No brownouts | Stable |
| Uploads complete successfully | Stable |
| Long recordings remain stable | Stable |

---

# Common Power System Issues

| Problem | Possible Cause | Suggested Fix |
| --- | --- | --- |
| ESP32 resets during upload | Voltage sag | Improve battery/current delivery |
| SD corruption | Unstable power rail | Improve regulation |
| TP4056 overheating | Incorrect wiring | Verify polarity |
| MT3608 output unstable | Poor adjustment | Recalibrate output voltage |
| Device does not boot | Incorrect output voltage | Measure with multimeter |
| Random reboot loops | Weak USB/battery supply  | Improve power source |

---

# Recommended Next Step

Once the portable power subsystem is validated successfully, proceed to backend infrastructure deployment.

Continue to:

→ [Backend Deployment Guide](../04-backend/deployment-guide.md)

Then:

→ [Shared Drive Setup Guide](../04-backend/shared-drive-integration.md)

---

# Additional Resources

## ESP32 Power Guidelines

* [ESP32 Hardware Design Guidelines](https://docs.espressif.com/projects/esp-hardware-design-guidelines/en/latest/esp32/esp-hardware-design-guidelines-en-master-esp32.pdf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)

## TP4056 Overview

* [TP4056 Module Overview](https://components101.com/modules/tp4056a-li-ion-battery-chargingdischarging-module?utm_source=chatgpt.com)

## MT3608 Overview

* [MT3608 Boost Converter Overview](https://components101.com/modules/mt3608-2a-dc-dc-step-up-power-module?utm_source=chatgpt.com)

## Multimeter Basics

* [How to Use a Multimeter](https://learn.sparkfun.com/tutorials/how-to-use-a-multimeter/all?utm_source=chatgpt.com)

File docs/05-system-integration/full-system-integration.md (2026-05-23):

# Full System Integration Guide

This section documents the final integration workflow of the Audionote system.

At this stage:

* firmware,
* hardware,
* power management,
* cloud backend,
* transcription services,
* and Shared Drive infrastructure

are combined into a complete operational embedded lecture transcription system.

This stage transforms the project from:

* isolated subsystems

into:

* a fully functioning embedded cloud-connected device.

---

# System Integration Overview

The Audionote system integrates:

| Subsystem | Purpose |
| --- | --- |
| ESP32 Firmware | Device control & uploads |
| Audio Capture System | Lecture recording |
| Storage System | Local WAV storage |
| Power System | Portable operation |
| Backend Infrastructure | Cloud processing |
| Speech-to-Text Pipeline  | Transcription |
| Shared Drive Integration | Organization & archival  |
| Enclosure System | Physical deployment |

---

# Full System Architecture

```text id="0bo83y"
Lecturer Audio
        ↓
INMP441 Microphone
        ↓
ESP32 Audio Processing
        ↓
WAV File Storage (MicroSD)
        ↓
Wi-Fi Upload System
        ↓
Signed URL Backend
        ↓
Google Cloud Storage
        ↓
Auto-Transcription Backend
        ↓
Speech-to-Text Processing
        ↓
Google Shared Drive
```

---

# Before You Begin

Ensure all previous stages are completed successfully.

Required completed guides:

| Guide | Status |
| --- | --- |
| Firmware Setup | Completed |
| Hardware Assembly | Completed |
| Power System Guide | Completed |
| Backend Deployment | Completed |
| Shared Drive Integration | Completed |

---

# Recommended Validation Before Integration

Before final assembly:

| Validation Item | Expected Result |
| --- | --- |
| ESP32 boots reliably | Stable |
| INMP441 recording works | Functional |
| WAV files saved | Successful |
| SD card stable | Functional |
| Wi-Fi upload works | Functional |
| Backend deployment active | Functional |
| Transcription pipeline works | Functional |
| Shared Drive upload works | Functional |

---

# Stage 1 — Prepare the Hardware Subsystems

Gather the completed hardware modules:

| Module | Purpose |
| --- | --- |
| ESP32 Core Board | Main controller |
| INMP441 Microphone | Audio capture |
| SD Card Module | Local storage |
| Power System | Portable power |
| Push Button | Recording control |
| Switch System | Power management  |

---

# Recommended Pre-Assembly Checks

Before enclosure integration:

* transfer components from the breadbord to a veroboard (or similar) for permanent connections,
* inspect solder joints,
* verify wiring polarity,
* validate SD card operation,
* confirm stable ESP32 boot,
* and test battery output voltage.

---

# Recommended Wiring Validation

| Connection | Validation |
| --- | --- |
| I2S Wiring | Correct |
| SD SPI Wiring | Correct |
| Power Rails | Stable |
| Ground Connections | Common |
| Battery Polarity | Correct |

---

# Stage 2 — Validate Audio Recording System

Power the device and perform a short recording test.

### Major Notes:

* After full assembly, I noticed that I needed to scratch between the SD card solder connection lines on the main veroboard. I think this is due to cross-talk of the SD communication lines even though I verified zero continuity between the soldering connection lines.

* I also noticed that the INMP441 microphone sometimes wasn't outputting the right data, despite verifying that the right connections were made and continuity. I found that tying the microphone connection wires together closely solved this.

  This is some form of noise cancellation, shielding, or signal integrity management. By bundling or twisting your I2S wires (especially clock and data lines) together, you effectively create a rudimentary shielded twisted pair. This technique reduces electromagnetic interference (EMI) and crosstalk, ensuring that digital signals remain clean.

* In my hardware development, I used long female-to-male jumper wires. I initially tried connecting different wires to make it long enough for the main device to be attached somewhere around the waist, while the mic was positioned at the collar side, all to fit the originally intended form factor. I found out two things:
  1. Many jumper wires in the collections don't work well. Test for continuity before using them in your connections, especially the permanent ones.
  2. The signals found it hard to transmit to the ESP32 board. However, I know a fellow innovator who built a keyword speech-to-text recognition system for some short phrase commands using Raspberry Pi 3 (I think), and he did have very long wires connected to his INMP441 mic. I didn't verify again whether the long wires would work for mine. You can try verifying and share your feedback.

# Recording Validation Workflow

```text id="rq1cmv"
Power On
    ↓
Initialize ESP32
    ↓
Initialize SD Card
    ↓
Initialize I2S Microphone
    ↓
Start Recording
    ↓
Generate WAV File
```

---

# Recommended Validation

| Test | Expected Result |
| --- | --- |
| ESP32 initializes | Successful |
| Microphone detected | Successful |
| SD card mounted | Successful |
| WAV file created | Successful |
| Recording duration accurate | Successful |

---

# Recommended Debugging Tools

Useful tools include:

| Tool | Purpose |
| --- | --- |
| Arduino Serial Monitor | Firmware debugging |
| Cloud Logging | Backend debugging |
| Multimeter | Voltage verification |
| SD Card Reader | File inspection |

---

# Arduino Serial Monitor

Use the Arduino Serial Monitor to validate:

* initialization logs,
* Wi-Fi connection,
* upload status,
* and runtime behavior.

Arduino IDE:

* [Arduino IDE Documentation](https://docs.arduino.cc/software/ide-v2?utm_source=chatgpt.com)

---

# Stage 3 — Validate Upload System

Once recording succeeds:

1. stop recording,
2. enable Wi-Fi access,
3. and monitor upload behavior.

---

# Upload Workflow

```text id="00d8qf"
Recording Stops
        ↓
Wi-Fi Detected
        ↓
Signed URL Requested
        ↓
Chunked Upload Begins
        ↓
WAV Stored in Cloud Storage
```

---

# Recommended Validation

| Test | Expected Result |
| --- | --- |
| Wi-Fi connection succeeds | Functional |
| Signed URL received | Functional |
| Upload completes | Successful |
| WAV visible in bucket | Successful |

---

# Recommended Cloud Storage Verification

Open:

* [Google Cloud Storage Console](https://console.cloud.google.com/storage/browser?utm_source=chatgpt.com)

Verify:

* uploaded WAV file exists,
* file size is valid,
* and upload timestamps are correct.

---

# Stage 4 — Validate Automatic Transcription

Once uploads succeed, validate:

* backend triggers,
* Speech-to-Text processing,
* and transcript generation.

---

# Transcription Workflow

```text id="4rdb5l"
WAV Uploaded
        ↓
Storage Trigger Fires
        ↓
Auto-Transcription Backend Executes
        ↓
Speech-to-Text API Processes Audio
        ↓
Transcript Generated
```

---

# Optional Backend Isolation Test — Manual Audio Upload

While testing the complete ESP32 upload workflow, it is recommended to validate the backend pipeline independently by manually uploading a WAV audio file directly into the Cloud Storage bucket.

This helps isolate backend functionality from firmware-related issues.

I found this especially useful when one of my longest duration recordings (20 mins) was cut off by the Wi-Fi instability and didn't fully upload to the backend. It would have been a chore to try to record the whole 20 minutes again so I opted to manually upload it to the backend.

---

# Why This Test Is Important

If the backend pipeline works correctly with a manually uploaded audio file, then:
- Cloud Storage is configured correctly,
- triggers are functioning,
- transcription services are operational,
- and Shared Drive integration is likely working properly.

This significantly simplifies debugging because:
- firmware upload issues can then be isolated independently.

---

# Recommended Testing Workflow

```text
Manual WAV Upload
        ↓
Cloud Storage Trigger Fires
        ↓
Auto-Transcription Backend Executes
        ↓
Transcript Generated
        ↓
Shared Drive Updated
```

---

# Step 1 — Prepare a Test WAV File

Use:
- a short lecture recording,
- microphone sample,
- or exported WAV file.

Recommended:
- short duration initially (10–30 seconds),
- mono audio,
- WAV format,
- and speech-focused content.

---

# Recommended Audio Properties

| Parameter | Recommendation |
|---|---|
| Format | WAV |
| Encoding | LINEAR16 |
| Channels | Mono |
| Duration | 10–30 seconds initially |

---

# Step 2 — Open the Cloud Storage Bucket

Open:

- :contentReference[oaicite:0]{index=0}

Then:
1. Open:
   ```text
   audionote-recordings
   ```
2. Navigate into the desired upload folder

Example:

```text
lectures/test-session/
```

---

# Step 3 — Upload the WAV File

Inside the bucket:

1. Click:
   ```text
   UPLOAD FILES
   ```
2. Select the WAV file
3. Wait for upload completion

---

# Expected Backend Behavior

Once upload completes:

```text
Cloud Storage Detects Upload
        ↓
Eventarc Trigger Fires
        ↓
Auto-Transcription Backend Starts
        ↓
Speech-to-Text Processes Audio
        ↓
Transcript Generated
```

---

# Step 4 — Monitor Backend Logs

Useful debugging command:

```bash
gcloud functions logs read autoTranscribeOnUpload --gen2 --region=europe-west1
```

This helps confirm:
- trigger activation,
- backend execution,
- and transcription processing.

---

# Google Cloud Logging Console

You can also inspect logs visually:

- :contentReference[oaicite:1]{index=1}

---

# Step 5 — Validate Generated Outputs

Verify:

| Validation Item | Expected Result |
|---|---|
| WAV exists in bucket | Successful |
| Trigger activates | Successful |
| Backend executes | Successful |
| Transcript generated | Successful |
| Shared Drive updated | Successful |

---

# Important Engineering Advantage

This testing method is extremely useful because it separates:

| System | Validation Focus |
|---|---|
| Backend infrastructure | Cloud functionality |
| ESP32 firmware | Embedded upload logic |

This makes debugging significantly easier.

---

# Recommended Debugging Strategy

Always validate:
1. backend infrastructure first,
2. then firmware uploads second.

This prevents:
- debugging multiple failure points simultaneously,
- and significantly reduces development complexity.

---

# Recommended Development Mindset

When working on distributed embedded systems:
- isolate subsystems,
- validate incrementally,
- and avoid debugging the entire architecture at once.

This is standard engineering practice in:
- IoT systems,
- cloud-connected embedded devices,
- and distributed automation systems.

---

# Recommended Validation

| Test | Expected Result |
| --- | --- |
| Trigger activates | Successful |
| Backend executes | Successful |
| Transcript generated | Successful |
| No backend crash | Stable |

---

# Backend Log Monitoring

Useful debugging command:

```bash id="dx1w3d"
gcloud functions logs read autoTranscribeOnUpload --gen2 --region=europe-west1
```

This helps diagnose:

* backend failures,
* trigger issues,
* transcription errors,
* and permission problems.

---

# Google Cloud Logging Console

* [Google Cloud Logging Console](https://console.cloud.google.com/logs?utm_source=chatgpt.com)

---

# Stage 5 — Validate Shared Drive Integration

Verify:

* transcript uploads,
* folder organization,
* and automated archival.

---

# Shared Drive Workflow

```text id="1o7zwr"
Transcript Generated
        ↓
Folder Created Automatically
        ↓
Transcript Uploaded
        ↓
Metadata Organized
```

---

# Recommended Validation

| Test | Expected Result |
| --- | --- |
| Shared Drive accessible  | Functional |
| Transcript uploaded | Successful |
| Folder structure correct | Organized |
| Metadata stored | Functional |

---

# Stage 6 — Integrate Into the Enclosure

Once all electronic systems are validated individually, begin enclosure integration.

---

# Recommended Enclosure Goals

The enclosure should:

* protect internal components,
* stabilize wiring,
* support portability,
* and reduce strain on solder joints.

---

# Enclosure Options

| Option | Description |
| --- | --- |
| Initial Prototype Pattress | Fast prototyping |
| 3D Printed Enclosure | Cleaner final assembly |

---

# Enclosure Resources

Below are pictures of the initial Prototype in a pattress that would be useful for you to know how to position and structure the different components of your audionote system into the pattress.

<div align="center">

| Top View | R Side View <br> (With holes Mic wires & Button) | L Side View <br> (With slots for SD Card, <br> TP4056 charging port (upwards), and Power Switch) | Enclosed Top View | During Development View |
| :---: | :---: | :---: | :---: | :---: |
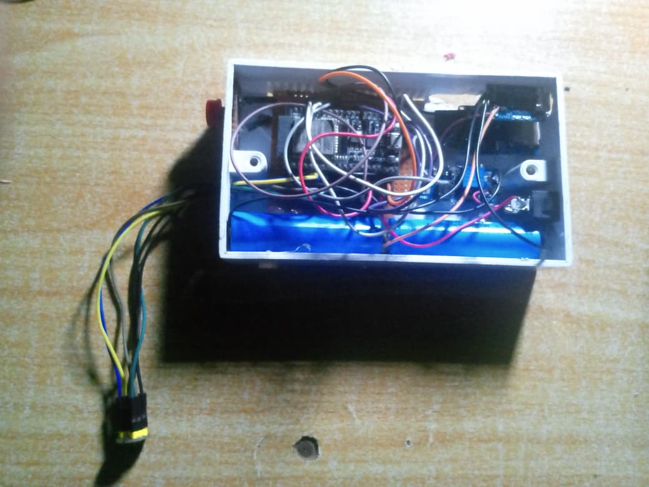
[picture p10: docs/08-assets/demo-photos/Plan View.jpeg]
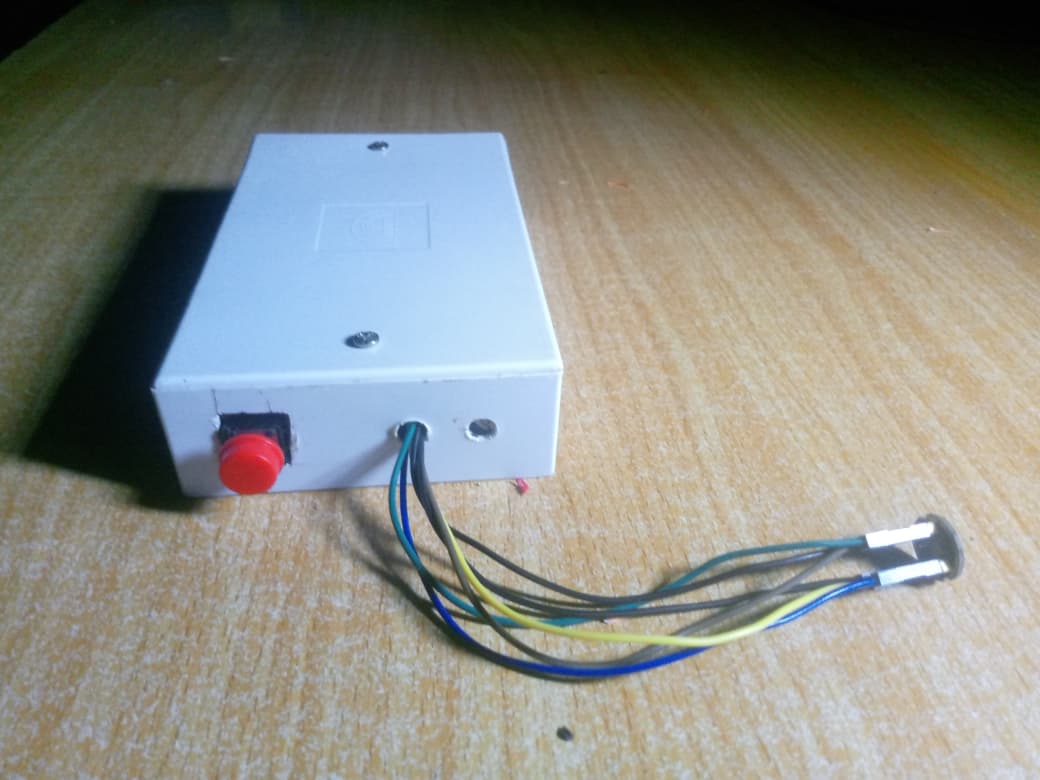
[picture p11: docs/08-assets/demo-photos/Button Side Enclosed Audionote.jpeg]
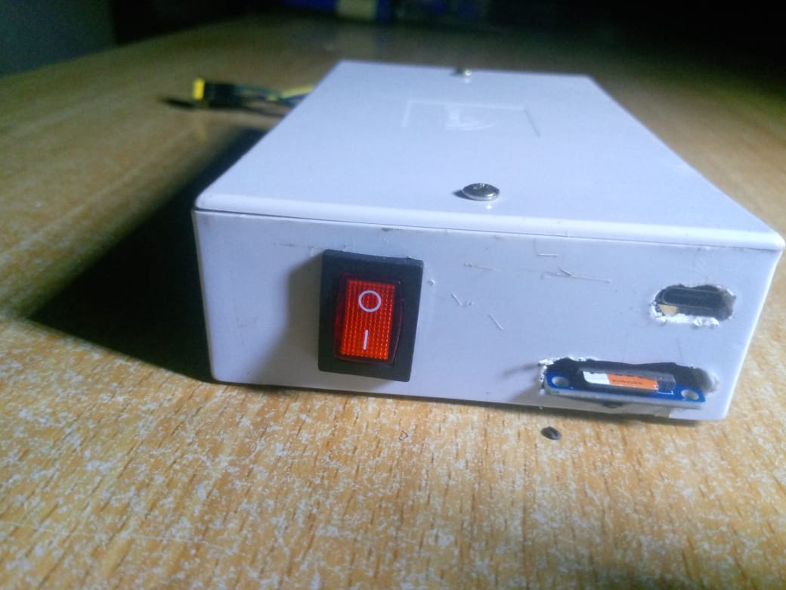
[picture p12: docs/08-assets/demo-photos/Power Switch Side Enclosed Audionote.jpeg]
|  |  |  |  |  |

</div>

* You can click the pictures for a wider view of each.

Also, here is a diagram showing how different components were positioned within the pattress:

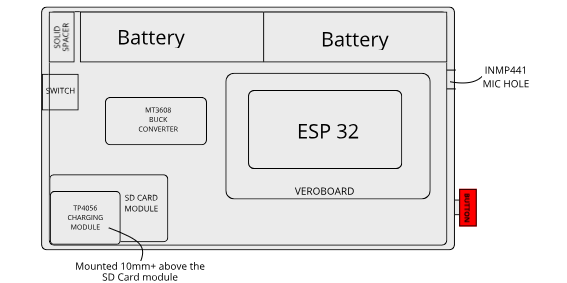
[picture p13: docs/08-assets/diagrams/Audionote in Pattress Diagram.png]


You can also find the 3d printable files here:

→ [3D Printable Files](/hardware/enclosure) designed by a friend, [Elias](https://github.com/buildwithelias)

---

# Important Assembly Notes

During enclosure integration:

* avoid wire tension,
* avoid exposed conductive surfaces,
* secure batteries properly,
* and isolate power circuitry carefully.

---

# Recommended Mechanical Stabilization

Useful materials:

| Material | Purpose |
| --- | --- |
| Hot Glue | Wire stabilization  |
| Heat Shrink | Insulation |
| Zip Ties | Cable management |
| Vero Board  | Structural mounting |

---

# Stage 7 — Validate Portable Operation

Test the system:

* disconnected from USB,
* fully battery powered,
* and in realistic operating conditions.

---

# Recommended Portable Test Workflow

```text id="cqht3j"
Battery Power
        ↓
ESP32 Boot
        ↓
Lecture Recording
        ↓
WAV Storage
        ↓
Wi-Fi Upload
        ↓
Cloud Processing
```

---

# Recommended Portable Validation

| Test | Expected Result |
| --- | --- |
| Stable boot | Successful |
| No random resets | Stable |
| Recording stable | Functional |
| Upload stable | Functional |
| Battery runtime acceptable | Functional |

---

# Stage 8 — Evaluate Long Recording Stability

Perform extended-duration recording tests.

Recommended:

* 15–30 minute recordings initially. Try incrementally pushing it past this limits and see what happens too. 😊

---

# Important Engineering Considerations

Long recordings help validate:

* SD card stability,
* memory behavior,
* power reliability,
* upload recovery,
* and thermal behavior.

---

# Stage 9 — Final System Validation

Perform complete end-to-end workflow tests. Multiple ones. Log them in a Google Sheet file.

---

# End-to-End Workflow

```text id="rvgq3o"
Lecture Begins
        ↓
Audio Recorded
        ↓
WAV Stored
        ↓
Recording Stops
        ↓
Wi-Fi Upload Begins
        ↓
Backend Processing
        ↓
Transcript Generated
        ↓
Shared Drive Updated
```

---

# Final Validation Checklist

| Validation Item | Expected Result |
| --- | --- |
| Audio quality acceptable | Successful |
| WAV integrity valid | Successful |
| Upload stable | Successful |
| Backend stable | Successful |
| Transcript accuracy acceptable  | Functional |
| Shared Drive organization works | Functional |
| Portable operation stable | Successful |

---

# Important Engineering Note

This integration stage is where:

* embedded systems,
* cloud infrastructure,
* event-driven architecture,
* and real-world deployment constraints

all converge simultaneously.

It is completely normal to encounter:

* intermittent bugs,
* integration mismatches,
* upload instability,
* timing issues,
* or backend synchronization problems during this phase.

---

# Recommended Debugging Mindset

Debug incrementally.

Avoid changing multiple systems simultaneously.

Recommended strategy:

```text id="b76gpt"
Validate Hardware
        ↓
Validate Firmware
        ↓
Validate Upload
        ↓
Validate Backend
        ↓
Validate Transcription
        ↓
Validate Shared Drive
```

---

# Using AI Assistance in Cloud Shell Editor

Google Cloud Shell Editor includes built-in AI assistance.

Shortcut:

```text id="8s02tr"
Alt + G
```

Useful for:

* deployment troubleshooting,
* log interpretation,
* IAM debugging,
* and backend error analysis.

---

# Recommended Future Upgrades

Potential future system improvements:

| Upgrade | Purpose |
| --- | --- |
| OTA Firmware Updates | Remote firmware management |
| Advanced STT Model Integration| Improved transcription |
| PCB Version | Cleaner production design |
| Battery Monitoring | Improved portability |
| Speaker Diarization | Multi-speaker identification |
| Local AI Models | Reduced cloud dependency |

---

# Community Contributions

You are encouraged to:

* improve transcription workflows,
* experiment with alternative STT models,
* optimize power systems,
* improve enclosure design,
* and contribute backend improvements.

---

# Sharing Your Build

If you recreate or improve the system:

* share images,
* upload modifications,
* document improvements,
* and contribute fixes back to the repository.

Potential contribution areas include:

* firmware optimization,
* cloud scalability,
* UI dashboards,
* and mechanical design improvements.

Continue to:

→ [Contribution Guidelines](/CONTRIBUTING.md)

---

# Recommended Next Step

Once full system integration is validated successfully:

Continue to:

→ [Engineering Analysis](../06-analysis/engineering-analysis.md)

---

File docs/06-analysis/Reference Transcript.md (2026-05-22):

Title: Introduction to Embedded Systems and Real-Time Data Processing

Good day everyone. In this lecture, we will introduce the concept of embedded systems and explain why they are important in modern engineering applications. Embedded systems are specialized computing systems designed to perform specific tasks within larger electrical or mechanical systems. Unlike general-purpose computers, they are optimized for reliability, efficiency, and real-time operation.

Embedded systems are widely used in everyday devices such as smartphones, washing machines, medical equipment, and automotive control units. At the core of most embedded systems is a microcontroller or microprocessor, which interacts with sensors, actuators, memory modules, and communication interfaces.

One key characteristic of embedded systems is their ability to respond to inputs within strict timing constraints. This requirement is referred to as real-time performance. In real-time systems, delayed responses can lead to degraded performance or complete system failure, especially in safety-critical applications.

To better understand embedded systems, it is useful to examine their major components. These typically include a processing unit, input devices such as sensors, output devices such as displays or motors, and storage components like flash memory or SD cards

The processing unit executes firmware, which is a specialized form of software written to directly control hardware resources. Firmware is often developed using languages such as C or C++ and is optimized to run efficiently within limited memory and power constraints.

Another important aspect of embedded system design is power management. Many embedded devices operate on batteries, making energy efficiency a critical design goal. Engineers must carefully balance performance, power consumption, and system responsiveness.

Communication is also essential in modern embedded systems. Devices often need to transmit data to external systems or cloud platforms using protocols such as Wi-Fi, Bluetooth, or cellular networks. This connectivity enables applications like remote monitoring, data logging, and cloud-based data processing.

In recent years, embedded systems have become increasingly integrated with artificial intelligence and machine learning techniques. For example, speech recognition, image processing, and predictive maintenance systems are now commonly deployed on embedded platforms.

One practical application of embedded systems combined with cloud computing is automated lecture transcription. In such systems, audio is captured using microphones connected to a microcontroller. The recorded audio is stored locally and later transmitted to a cloud-based server for speech-to-text processing.

This approach allows the embedded device to remain lightweight while leveraging powerful cloud resources for computation-intensive tasks such as automatic speech recognition. However, it introduces challenges related to network reliability, data latency, and privacy.

Designers must also consider how users interact with the device. Simple interfaces such as push buttons and indicator LEDs are often preferred to reduce complexity and improve usability. The system should provide clear feedback to the user during recording, storage, and data transmission phases.

Error handling is another critical concern. For instance, the system should be able to recover gracefully from SD card failures, power interruptions, or network disconnections. Robust error handling improves reliability and ensures that valuable data is not lost. 

Beyond technical considerations, embedded systems also play an important role in education and accessibility. Automated transcription systems can help students review lectures, support learners with hearing impairments, and improve knowledge retention.

When designing such systems for classroom environments, engineers must account for background noise, varying speaker accents, and differences in speaking pace. These factors significantly affect transcription accuracy and overall system performance.

Testing and evaluation are therefore essential stages of system development. Engineers evaluate audio quality, transcription accuracy, latency, power consumption, and user experience to determine whether the system meets its design objectives.

In conclusion, embedded systems form the backbone of many modern technologies. By combining efficient hardware design with cloud-based services, it is possible to build practical, scalable, and user-friendly solutions such as real-time or asynchronous lecture transcription devices. Continued advancements in embedded processing and artificial intelligence will further expand the capabilities and applications of these systems.

Good day everyone, and welcome to today’s lecture on embedded systems, real-time processing, and cloud-based speech recognition systems. In this session, we will explore the fundamental principles of embedded system design, examine how real-time constraints influence system performance, and discuss how cloud computing can be integrated to enable advanced applications such as automated lecture transcription.

Embedded systems are specialized computing systems designed to perform specific functions within a larger mechanical or electrical system. Unlike general-purpose computers, embedded systems are optimized for efficiency, reliability, and predictable performance. They are typically built around microcontrollers or microprocessors that interact directly with sensors, actuators, memory modules, and communication interfaces.

Common examples of embedded systems include smart home devices, medical monitoring equipment, automotive control systems, industrial automation controllers, and wearable electronics. In all these applications, the embedded system performs a dedicated task, often under strict timing, power, and memory constraints.

One defining feature of embedded systems is their interaction with the physical environment. Sensors convert physical signals such as sound, temperature, pressure, or motion into electrical signals that can be processed digitally. Actuators then convert processed signals into physical actions, such as motor movement, light emission, or sound generation.

Another important characteristic is real-time operation. A real-time system is one in which the correctness of operations depends not only on logical results but also on the time at which outputs are produced. In hard real-time systems, missing a deadline may lead to catastrophic failure, as seen in medical life-support machines or aircraft control systems. In soft real-time systems, delays degrade performance but do not necessarily cause total system failure, such as in multimedia streaming or voice-controlled interfaces.

The design of real-time embedded systems therefore requires careful planning. Engineers must analyze system timing, select appropriate hardware platforms, optimize software algorithms, and ensure reliable communication between system components. Task scheduling, interrupt handling, and memory management play crucial roles in ensuring that time-critical operations are completed within their deadlines.

Power management is another central design consideration. Many embedded systems are battery-powered and must operate for extended periods without recharging. As a result, engineers strive to minimize energy consumption by using low-power components, optimizing firmware execution, and implementing intelligent sleep and wake cycles. Communication modules, particularly Wi-Fi and cellular radios, are known to be major contributors to power consumption, and their use must be carefully managed.

In recent years, embedded systems have increasingly integrated artificial intelligence and machine learning techniques. These advancements have enabled capabilities such as speech recognition, facial recognition, object detection, and predictive maintenance. However, deploying AI algorithms directly on low-power microcontrollers remains challenging due to computational and memory constraints. To overcome this limitation, many systems adopt a hybrid approach that combines local data acquisition with cloud-based processing.

Cloud computing provides virtually unlimited computational resources, enabling complex tasks such as large-scale speech recognition, deep learning inference, and big data analytics. In a cloud-assisted embedded system, data is captured locally, transmitted over a network, and processed remotely. The processed results are then returned to the embedded device or stored for later retrieval.

This architecture is particularly useful in lecture transcription systems. In such systems, audio is recorded using microphones connected to a microcontroller. The captured audio is stored locally, often on an SD card, before being transmitted to a cloud-based automatic speech recognition service. The ASR engine converts the audio into text, which can then be archived, indexed, and shared with students.

One key advantage of this approach is scalability. Cloud-based ASR services can handle varying workloads and support multiple users simultaneously. This makes them suitable for large lecture halls, conference environments, and online learning platforms. Additionally, cloud services benefit from continuous model updates, which improve recognition accuracy over time without requiring hardware modifications.

However, cloud-based processing introduces new challenges. Network latency can significantly affect system responsiveness, especially in regions with unstable internet connectivity. Packet loss, bandwidth limitations, and temporary outages may lead to delayed or incomplete transcription. Therefore, embedded devices must be designed to handle intermittent connectivity gracefully.

One solution is asynchronous data transmission. In this approach, audio is recorded and stored locally before being uploaded when network conditions are favorable. This method ensures that recording functionality is not disrupted by temporary connectivity issues. It also allows batch uploading and processing, which can improve energy efficiency and reduce transmission overhead.

Storage management is equally important. Audio recordings can consume significant memory, especially at higher sampling rates and bit depths. Engineers must select appropriate compression formats and storage capacities to balance audio quality with storage efficiency. File organization strategies, such as timestamp-based directory structures, help ensure easy retrieval and traceability of recordings.

User interaction design plays a crucial role in the practical adoption of embedded transcription devices. Simplicity and clarity are essential. A minimal interface consisting of a start button, stop button, and status indicator can significantly reduce user errors. Visual or auditory feedback mechanisms help users confirm that recording, storage, and transmission processes are functioning correctly.

From a usability perspective, the device should be operable without extensive training. In a classroom environment, lecturers and students should be able to activate recording with minimal distraction. The system should also provide clear indications of errors, such as storage failure or network unavailability, so that corrective actions can be taken promptly.

Reliability and fault tolerance are critical factors in embedded system design. The system must be able to handle unexpected events such as power loss, memory corruption, or peripheral malfunction. Error detection and recovery mechanisms should be incorporated into both firmware and software components to prevent data loss and system crashes.

For example, when an SD card is removed during recording, the system should immediately halt writing operations and notify the user. Similarly, if network transmission fails, the system should retry automatically after a predefined interval. Watchdog timers may also be used to reset the system in the event of firmware lock-up.

Testing and evaluation are essential phases in system development. Engineers must assess performance metrics such as latency, throughput, power consumption, audio quality, transcription accuracy, and system reliability. These metrics provide quantitative and qualitative insights into how well the system meets its design objectives.

Latency evaluation measures the delay between initiating a recording and receiving the corresponding transcript. This delay is influenced by audio duration, network bandwidth, and cloud processing speed. Throughput analysis examines how much audio data can be processed within a given time frame. Power evaluation focuses on energy usage patterns across different operational states.

Transcription accuracy is commonly measured using the Word Error Rate metric, which quantifies differences between reference and recognized transcripts. Factors affecting accuracy include background noise, microphone placement, speaker accent, speaking rate, and environmental acoustics. Accent variability is particularly important in multilingual and multicultural contexts, where speech patterns differ significantly from the training data used in ASR models.

In Nigeria and other African countries, speech recognition systems often face challenges due to limited representation of local accents in training datasets. As a result, transcription errors may occur, especially for proper nouns, technical terminology, and indigenous names. Continuous dataset expansion and model fine-tuning are necessary to improve recognition performance in such contexts.

Educational institutions stand to benefit significantly from automated transcription systems. Recorded and transcribed lectures allow students to revisit complex concepts, support learners with hearing impairments, and improve overall comprehension. Archived transcripts can also be indexed and searched, enabling rapid retrieval of specific topics.

Beyond education, similar systems can be applied in journalism, legal documentation, medical reporting, and corporate meetings. In all these applications, the combination of embedded systems and cloud-based speech recognition offers a cost-effective and scalable solution for real-time or near-real-time documentation.

As technology continues to advance, embedded devices are becoming more powerful, energy-efficient, and intelligent. Emerging microcontrollers now feature integrated wireless connectivity, hardware encryption, and specialized accelerators for machine learning workloads. These developments are expanding the range of feasible applications and reducing the dependence on external computing resources.

In conclusion, embedded systems play a central role in modern digital infrastructure. Their integration with cloud computing and artificial intelligence enables innovative applications such as automated lecture transcription. By carefully balancing performance, power efficiency, reliability, and usability, engineers can design practical systems that enhance learning experiences and improve access to information.

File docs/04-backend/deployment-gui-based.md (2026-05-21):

# Backend Deployment Guide (GUI-Based GCP Workflow)

This section documents how to deploy the Audionote backend infrastructure primarily using the Google Cloud Platform graphical interface (GUI), with minimal command-line usage.

This workflow is especially useful for:

* students,
* first-time cloud developers,
* embedded systems developers,
* and users unfamiliar with DevOps tooling.

The backend system is responsible for:

* generating secure upload URLs,
* receiving uploaded lecture recordings,
* triggering automatic transcription,
* organizing transcripts,
* and integrating with Google Shared Drive.

---

# Backend Architecture Overview

```text
ESP32 Device
        ↓
Signed URL Backend
        ↓
Google Cloud Storage
        ↓
Auto-Transcription Backend
        ↓
Google Speech-to-Text
        ↓
Google Shared Drive
```

---

# Before You Begin

Ensure the following stages are already completed:

* Firmware setup
* Hardware assembly
* Audio recording validation
* Upload system validation
* Power system integration

Continue from:

→ [Power System Guide](../02-hardware/power-system.md)

---

# Recommended Accounts & Requirements

| Requirement | Purpose |
| --- | --- |
| Google Account | GCP authentication |
| Debit/Card Payment Method | Billing verification  |
| Internet Connection | Backend deployment |
| Node.js (Optional) | Local backend testing |
| GitHub Repository / Downloaded Backend Files | Backend source code |

---

# Stage 1 — Create a Google Cloud Account

Open:

* [Google Cloud Console](https://console.cloud.google.com/?utm_source=chatgpt.com)

Sign in using your Google account.

---

# Google Cloud Free Credits

New Google Cloud accounts usually receive promotional credits for development and testing.

Learn more:

* [Google Cloud Free Tier & Credits](https://cloud.google.com/free?utm_source=chatgpt.com)

Important:

* Billing must still be enabled
* Usage quotas still apply

To avoid unexpected charges:

* use short recordings during testing,
* monitor storage usage,
* and configure billing alerts.

Billing alerts guide:

* [Google Cloud Budget Alerts Documentation](https://cloud.google.com/billing/docs/how-to/budgets?utm_source=chatgpt.com)

---

# Stage 2 — Create a Google Cloud Project

Inside the Google Cloud Console:

1. Click the project selector at the top navigation bar
2. Click:

   ```text
   NEW PROJECT
   ```
3. Enter a project name

Example:

```text
audionote-backend
```

4. Click:

   ```text
   CREATE
   ```

Wait for the project to initialize.

---

# Stage 3 — Enable Billing

Cloud Run and Speech-to-Text require billing to be enabled.

Open:

* [Google Cloud Billing Console](https://console.cloud.google.com/billing?utm_source=chatgpt.com)

Then:

1. Link a billing account
2. Add payment method
3. Attach billing account to your project

---

# Stage 4 — Enable Required APIs

Open:

* [Google Cloud API Library](https://console.cloud.google.com/apis/library?utm_source=chatgpt.com)

Enable the following APIs:

| API | Purpose |
| --- | --- |
| Cloud Run API | Backend hosting |
| Cloud Storage API  | File storage |
| Speech-to-Text API | Audio transcription |
| Google Drive API | Shared Drive integration |
| IAM API | Permissions management |
| Eventarc API | Storage trigger automation |

---

# How to Enable an API

For each API:

1. Search the API name
2. Open the API page
3. Click:

   ```text
   ENABLE
   ```

Repeat for all required APIs.

---

# Stage 5 — Create the Primary Storage Bucket

The primary storage bucket stores uploaded WAV lecture recordings.

Open:

* [Google Cloud Storage Console](https://console.cloud.google.com/storage/browser?utm_source=chatgpt.com)

---

# Create Bucket

1. Click:

   ```text
   CREATE
   ```
2. Enter bucket name

Example:

```text
audionote-recordings
```

Bucket names must be globally unique.

---

# Recommended Bucket Settings

| Setting | Recommendation |
| --- | --- |
| Access Control | Uniform |
| Storage Class  | Standard |
| Location Type  | Region |
| Public Access  | Disabled |

---

# Recommended Folder Structure

```text
lectures/
    └── level/
          └── course/
                └── session/
```

---

# Stage 6 — Create the Transcript Bucket (Recommended)

This bucket stores:

* generated transcripts,
* processed outputs,
* and exported text files.

---

# Create Second Bucket

Repeat the bucket creation process.

Example:

```text
audionote-transcripts
```

---

# Recommended Transcript Structure

```text
transcripts/
    └── level/
          └── course/
                └── session/
                      ├── transcript.txt
                      ├── metadata.json
                      └── summary.txt
```

---

# Stage 7 — Obtain the Backend Source Code

You can either:

* clone the repository,
* or manually upload the backend folders.

---

# Option 1 — Clone Repository

```bash
git clone https://github.com/Ayoo5/audionote
```

---

# Option 2 — Manual File Upload

Required folders:

```text
backend/
├── signedurl/
└── autotranscribe/
```

Each folder should contain:

```text
index.js
package.json
```

---

# Stage 8 — Open Google Cloud Shell Editor

Open:

* [Google Cloud Shell](https://shell.cloud.google.com/?utm_source=chatgpt.com)

Then open the Cloud Shell Editor.

Cloud Shell Editor documentation:

* [Google Cloud Shell Editor Overview](https://cloud.google.com/shell/docs/editor-overview?utm_source=chatgpt.com)

---

# Stage 9 — Upload Backend Files

Inside Cloud Shell Editor:

1. Create folders:

```text
backend/
├── signedurl/
└── autotranscribe/
```

2. Upload:

* index.js
* package.json
* additional config files

using drag-and-drop or upload menu.

---

# Stage 10 — Install Backend Dependencies

Open the Cloud Shell terminal.

Navigate into the signed URL service:

```bash
cd backend/signedurl
```

Install dependencies:

```bash
npm install
```

Repeat for the transcription backend:

```bash
cd ../autotranscribe
npm install
```

---

# Stage 11 — Deploy the Signed URL Backend

Navigate into:

```bash
backend/signedurl
```

Then deploy using Cloud Run:

```bash
gcloud run deploy signedurl-service \
  --source . \
  --region us-central1 \
  --allow-unauthenticated
```

---

# Deployment Configuration

During deployment:

| Prompt | Recommendation |
| --- | --- |
| Region | us-central1 |
| Allow unauthenticated | Yes |
| Build source | Yes |

---

# Expected Result

After deployment:

```text
Service URL:
https://signedurl-service-xxxxx.run.app
```

Save this URL.

---

# Stage 12 — Configure ESP32 Backend Endpoint

Update firmware:

```cpp
#define SIGNED_URL_ENDPOINT "https://your-cloud-run-url.run.app"
```

Then re-upload firmware to the ESP32.

---

# Stage 13 — Deploy the Auto-Transcription Backend

Navigate into:

```bash
backend/autotranscribe
```

Deploy:

```bash
gcloud run deploy autoTranscribeOnUpload \
  --source . \
  --region us-central1 \
  --allow-unauthenticated
```

---

# Stage 14 — Configure Storage Trigger Automation

The transcription service should trigger automatically when WAV files are uploaded.

---

# Open Eventarc

Open:

* [Google Eventarc Console](https://console.cloud.google.com/eventarc?utm_source=chatgpt.com)

---

# Create Trigger

1. Click:

   ```text
   CREATE TRIGGER
   ```

2. Configure:

| Setting | Recommendation |
| --- | --- |
| Event Provider | Cloud Storage |
| Event Type | Object Finalized |
| Bucket | audionote-recordings |
| Destination | Cloud Run |
| Service | autoTranscribeOnUpload |

---

# Trigger Workflow

```text
ESP32 Upload
        ↓
Storage Bucket
        ↓
Eventarc Trigger
        ↓
Auto-Transcription Backend
        ↓
Transcript Generation
```

---

# Stage 15 — Configure IAM Permissions

Open:

* [Google Cloud IAM Console](https://console.cloud.google.com/iam-admin/iam?utm_source=chatgpt.com)

---

# Recommended Roles

| Role | Purpose |
| --- | --- |
| Storage Admin | Bucket access |
| Cloud Run Admin | Backend management |
| Speech-to-Text User  | Transcription access |
| Service Account User | Service execution |

---

# Stage 16 — Configure Speech-to-Text Processing

Audionote currently uses:

* post-recording batch transcription.

The backend:

1. receives uploaded WAV files,
2. processes transcription asynchronously,
3. stores transcript outputs.

Speech-to-Text documentation:

* [Google Speech-to-Text Documentation](https://cloud.google.com/speech-to-text/docs?utm_source=chatgpt.com)

---

# Recommended Audio Configuration

| Parameter | Recommendation |
| --- | --- |
| Encoding | LINEAR16 |
| Audio Format | WAV |
| Channels | Mono |
| Sample Rate  | Match firmware configuration |

---

# Stage 17 — Validate the Full Backend Pipeline

Perform a short recording test.

Expected workflow:

```text
ESP32 Recording
        ↓
Upload to Bucket
        ↓
Signed URL Validation
        ↓
Storage Trigger Fires
        ↓
Transcription Backend Runs
        ↓
Transcript Generated
```

---

# Recommended Validation Checklist

| Validation Item | Expected Result |
| --- | --- |
| Upload succeeds | Successful |
| WAV stored in bucket | Successful |
| Trigger activates | Successful |
| Transcript generated | Successful |
| No backend crashes | Stable |

---

# Important Engineering Note — Backend Integration & Debugging

The backend deployment and integration stage is the most technically demanding part of the Audionote system.

This stage combines multiple distributed systems simultaneously:

- embedded firmware,
- cloud infrastructure,
- event-driven backend triggers,
- asynchronous uploads,
- authentication systems,
- transcription APIs,
- and storage automation.

Because of this, it is completely normal to encounter:
- deployment errors,
- permission issues,
- upload failures,
- API configuration problems,
- trigger failures,
- authentication mismatches,
- or inconsistent backend behavior during development.

---

# Expect Significant Debugging

Unlike simple frontend or static software projects, Audionote is a full-stack embedded cloud system.

A single issue may originate from:
- firmware configuration,
- incorrect backend endpoints,
- bucket permissions,
- IAM roles,
- malformed uploads,
- transcription configuration,
- or trigger automation.

Debugging often requires:
- reading logs carefully,
- testing incrementally,
- isolating subsystems,
- and validating one stage at a time.

Patience and perseverance are extremely important during this stage.

---

# Recommended Development Strategy

Avoid changing multiple systems simultaneously.

Instead:

```text
Validate Firmware
        ↓
Validate Upload
        ↓
Validate Bucket Storage
        ↓
Validate Trigger Activation
        ↓
Validate Transcription
        ↓
Validate Shared Drive Integration
```

This makes debugging significantly easier.

---

# Reading Backend Logs

Cloud logs are one of the most important debugging tools during development.

Useful command:

```bash
gcloud functions logs read autoTranscribeOnUpload --gen2 --region=europe-west1
```

This can help diagnose:
- trigger failures,
- backend crashes,
- permission problems,
- transcription issues,
- and deployment errors.

---

# Google Cloud Logging Console

You can also inspect logs visually through the Google Cloud console:

* [Google Cloud Logging Console](https://console.cloud.google.com/logs?utm_source=chatgpt.com)

Useful for:
- real-time debugging,
- filtering backend events,
- and monitoring deployment behavior.

---

# Using Built-In Gemini AI Chat side panel

Google Cloud Platform (GCP) console includes built-in AI assistance which can help explain:
- deployment errors,
- terminal issues,
- IAM problems,
- Node.js errors,
- and Cloud Run failures.

Shortcut:

```text
Alt + G
```

This opens the integrated AI assistance panel.

This can be surprisingly useful for:
- interpreting logs,
- understanding error messages,
- and troubleshooting deployment problems during development.

---

# Important Mindset During Development

Large engineering systems rarely work perfectly on the first deployment.

The debugging process itself is part of the engineering experience.

Working through:
- infrastructure problems,
- firmware integration issues,
- asynchronous backend behavior,
- and cloud deployment challenges

develops valuable real-world systems engineering skills.

---

# Recommended Best Practices

| Best Practice | Why It Helps |
|---|---|
| Test incrementally | Easier debugging |
| Read logs frequently | Faster issue isolation |
| Validate one subsystem at a time | Prevents cascading failures |
| Use small test recordings initially | Reduces upload complexity |
| Keep backup firmware versions | Easier rollback |
| Document working configurations | Prevents regression |

---

# Engineering Reality

Backend-cloud integration for embedded systems can sometimes take longer to debug than building the hardware itself.

This is normal.

Successfully integrating:
- firmware,
- storage systems,
- cloud infrastructure,
- event automation,
- and transcription pipelines

is already a strong demonstration of practical engineering capability.

---

# Common Backend Issues

| Problem | Possible Cause | Suggested Fix |
| --- | --- | --- |
| Upload rejected | Invalid signed URL | Verify endpoint |
| Trigger not firing | Incorrect Eventarc setup | Reconfigure trigger |
| STT failure | API disabled | Enable Speech API |
| Permission denied | IAM issue | Verify service account roles |
| Backend deployment fails | Billing disabled | Enable billing |
| Cloud Run timeout | Large file processing | Optimize processing pipeline |

---

# Recommended Next Step

Once the backend deployment and automation pipeline are validated successfully, proceed to Shared Drive integration.

Continue to:

→ [Shared Drive Setup Guide](shared-drive-integration.md)

Then:

→ [Final System Integration](../05-system-integration/full-system-integration.md)

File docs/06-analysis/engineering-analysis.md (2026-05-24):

# Engineering Analysis

This section documents the engineering evaluation, testing methodology, system performance observations, and analytical workflow used during the development of the Audionote system.

The goal of this analysis is to:

* evaluate real-world system behavior,
* measure performance characteristics,
* identify system limitations,
* validate architecture decisions,
* and document system behavior observed during development.

This section also documents the workflow used to:

* export backend-generated metadata,
* organize evaluation datasets,
* compute latency and throughput metrics,
* and analyze transcription performance using Google Sheets.

---

# Analysis Objectives

The engineering analysis focused on evaluating:

| Evaluation Area | Purpose |
| --- | --- |
| Audio Storage Efficiency | Storage optimization |
| Upload Performance | Cloud transfer reliability |
| Transcription Latency | Backend responsiveness |
| Throughput Performance | End-to-end efficiency |
| File Integrity | Reliability |
| Folder Organization Accuracy | Backend automation validation |
| System Stability | Long-duration operation |

---

# Analysis Workflow Overview

```text id="if72ta"
Lecture Recording
        ↓
WAV Upload
        ↓
Cloud Processing
        ↓
Transcript Generation
        ↓
Metadata Export
        ↓
Google Sheets Analysis
        ↓
Performance Evaluation
```

---

# Sample Validation Transcripts

The engineering analysis utilized a reference transcript dataset to compare:

* generated transcript outputs,
* timing behavior,
* and system consistency.

---

# Reference Transcript Resource

→ [Reference Transcript Dataset](/docs/06-analysis/Reference%20Transcript.md)

These sample transcripts were used for informal consistency checks and engineering evaluation during development.

---

# Engineering Metrics Collected

The following metrics were tracked during testing:

| Metric | Purpose |
| --- | --- |
| Recording ID | Session tracking |
| Audio Size (MB) | Storage analysis |
| Audio Duration (Minutes) | Runtime analysis |
| Storage Efficiency (MB/min)  | Compression efficiency evaluation |
| Corrupted Files | Reliability evaluation |
| Audio Size (B) | Byte-level precision |
| Transcript Size (B) | Transcript scaling analysis |
| Audio Duration (Seconds) | Timing analysis |
| GCloud Created Datetime | Upload timestamp |
| Transcript Created Datetime  | Processing timestamp |
| Latency (Seconds) | Backend processing delay |
| Throughput (Seconds) | End-to-end system performance |
| File Organization Inaccuracy | Automation validation |

---

# Recommended Google Sheets Structure

Example columns:

```text id="8zcg8m"
Recording ID
Audio Size (MB)
Audio Duration (Minutes)
Storage Efficiency (MB/min)
Corrupted Files
Audio Size (B)
Transcript Size (B)
Audio Duration (Seconds)
GCloud Created Datetime
Transcript Created Datetime
Latency (Seconds)
Throughput (Seconds)
File Organization Inaccuracy
```

---

# Data Collection Workflow

The analysis workflow involved:

```text id="gcf39u"
Cloud Storage Metadata
        ↓
Transcript Metadata
        ↓
Export to Google Sheets
        ↓
Manual Validation
        ↓
Formula-Based Analysis
        ↓
Performance Evaluation
```

---

# Exporting Metadata to Google Sheets

The Audionote backend can be extended to:

* export metadata automatically,
* generate structured logs,
* and organize performance metrics inside Google Sheets.

---

# Recommended Workflow

```text id="66xk5u"
Backend Logs
        ↓
Metadata Extraction Script
        ↓
Google Sheets Export
```

---

# Suggested Metadata Fields

| Field | Description |
| --- | --- |
| Recording Name | Uploaded WAV identifier |
| Upload Timestamp | Cloud upload time |
| Transcript Timestamp | Transcript completion time |
| File Size | WAV file size |
| Transcript Size | Transcript output size |
| Upload Status | Success/failure |
| Folder Accuracy | Organizational validation  |

---

# Exporting Storage Bucket Data from Google Cloud

This section explains how to export recording metadata from Google Cloud Storage for engineering analysis inside Google Sheets.

The exported metadata can be used to analyze:
- upload latency,
- throughput,
- storage efficiency,
- transcript generation behavior,
- and overall backend performance.

---

# Recommended Export Workflow

```text
Google Cloud Storage
        ↓
Bucket Object Metadata
        ↓
CSV Export
        ↓
Google Sheets Import
        ↓
Engineering Analysis
```

---

# Option 1 — Export Using the Google Cloud Console (Beginner-Friendly)

Open:

- https://console.cloud.google.com/storage/browser

---

# Step 1 — Open the Storage Bucket

Navigate to:

```text
audionote-recordings
```

or your configured recording bucket.

---

# Step 2 — Open the Object List

Inside the bucket, you should see uploaded recordings such as:

```text
lectures/
    └── LEC145.wav
    └── LEC146.wav
```

Metadata visible includes:
- file size,
- upload timestamp,
- object name,
- storage class,
- and creation time.

---

# Step 3 — Copy Metadata into Google Sheets

Currently, Google Cloud Storage does not directly export bucket metadata into Sheets automatically from the GUI.

Recommended workflow:

1. Copy:
   - object names,
   - upload timestamps,
   - file sizes,
   - and recording identifiers

2. Paste them into:
   - Google Sheets

This is sufficient for small-to-medium engineering datasets.

---

# Option 2 — Export Bucket Metadata Using gsutil (Recommended)

This approach is more scalable and reproducible.

---

# Install Google Cloud SDK

- https://cloud.google.com/sdk/docs/install

---

# List Bucket Objects

```bash
gsutil ls -l gs://audionote-recordings/**
```

This outputs:
- file sizes,
- timestamps,
- and object paths.

---

# Example Output

```text
1468000  2026-01-29T06:34:17Z  gs://audionote-recordings/LEC145.wav
2516000  2026-01-29T06:36:14Z  gs://audionote-recordings/LEC146.wav
```

---

# Export Bucket Metadata to CSV

Example command:

```bash
gsutil ls -l gs://audionote-recordings/** > recordings_metadata.txt
```

Then manually:
1. clean the output,
2. convert to CSV,
3. and import into Google Sheets.

---

# Recommended Metadata Columns

| Field | Purpose |
|---|---|
| Object Name | Recording identifier |
| File Size | Storage analysis |
| Upload Timestamp | Latency analysis |
| Folder Path | Organization validation |

---

# Import into Google Sheets

Open:

- https://docs.google.com/spreadsheets/

Then:

```text
File
    ↓
Import
    ↓
Upload CSV
```

---

# Recommended Spreadsheet Workflow

```text
Bucket Metadata
        ↓
Google Sheets
        ↓
Derived Metrics
        ↓
Charts & Analysis
```

---

# Optional Python-Based Export Workflow

Advanced users may automate exports using:
- Python,
- pandas,
- and the Google Cloud Storage SDK.

Useful for:
- large datasets,
- repeated testing,
- and automated engineering evaluation pipelines.

---

# Google Cloud Storage SDK Documentation

- https://cloud.google.com/python/docs/reference/storage/latest

---

# Important Engineering Note

The analysis workflow intentionally combines:
- cloud metadata,
- backend timing behavior,
- transcript outputs,
- and manual engineering validation.

This hybrid workflow reflects real-world engineering analysis practices where:
- automation,
- scripting,
- and manual validation

are often used together.

---

# Google Sheets Setup

Open:

* [Google Sheets](https://docs.google.com/spreadsheets/?utm_source=chatgpt.com)

Create a spreadsheet for:

* performance metrics,
* upload logs,
* and transcription analysis.

---

# Recommended Sheet Organization

| Sheet | Purpose |
| --- | --- |
| Upload Metrics | Upload timing analysis |
| Transcript Metrics  | STT analysis |
| Error Logs | Failure tracking |
| Long-Duration Tests | Reliability analysis |

---

* Optional: Using Gemini Inside Google Sheets. It can help to: generate formulas, analyze datasets, compute derived columns, and assist with engineering observations.

---

# Recommended Spreadsheet Formulas

---

# 1. Storage Efficiency (MB/min)

Formula:

```excel id="dcdz4h"
=Audio_Size_MB / Audio_Duration_Minutes
```

Example:

```excel id="m6ayfi"
=B2/C2
```

---

# Purpose

This measures:

* how efficiently recordings utilize storage.

Lower values indicate:

* more storage-efficient recordings.

---

# 2. Audio Duration (Minutes)

Formula:

```excel id="n9b3z2"
=Audio_Duration_Seconds / 60
```

Example:

```excel id="mjlwm6"
=H2/60
```

---

# 3. Latency (Seconds)

Latency measures:

* the delay between upload completion
* and transcript generation.

Formula:

```excel id="6j90ka"
=(Transcript_Created_Datetime - GCloud_Created_Datetime) * 86400
```

Example:

```excel id="x8ht0e"
=(J2-I2)*86400
```

---

# Why Multiply by 86400?

Google Sheets stores datetime internally as days.

```text id="zvbk77"
86400 seconds = 1 day
```

Multiplication converts:

* days → seconds.

---

# 4. Throughput (Seconds)

This metric helps estimate how quickly the system processes recordings relative to recording duration.

Example formula:

```excel id="x6z8zw"
=Latency_Seconds / Audio_Duration_Seconds
```

Example:

```excel id="aogkij"
=K2/H2
```

---

# Throughput Interpretation

| Value | Interpretation |
| ----- | --- |
| < 1 | Faster than real-time |
| ≈ 1 | Real-time equivalent  |
| > 1 | Slower than real-time |

---

# 5. File Organization Inaccuracy

Recommended workflow:

* manually validate folder correctness,
* then assign binary values.

Example:

| Value | Meaning |
| ----- | --- |
| 0 | Correct organization |
| 1 | Incorrect organization |

---

# Example Formula

```excel id="ygxwbh"
=IF(ExpectedFolder=ActualFolder,0,1)
```

---

# 6. Corrupted Files Rate

Example formula:

```excel id="0izdgl"
=COUNTIF(D2:D100,"YES")/COUNTA(D2:D100)
```

---

# Recommended Analysis Visualizations

Useful charts include:

| Visualization | Purpose |
| --- | --- |
| Latency vs Duration | Backend scaling |
| Audio Size vs Duration | Storage efficiency |
| Throughput Trends | Processing efficiency |
| Error Frequency | Reliability analysis  |

---

# Google Sheets Chart Documentation

* [Google Sheets Chart Documentation](https://support.google.com/docs/answer/63824?utm_source=chatgpt.com)

---

# Recommended Testing Workflow

```text id="jlwm5w"
Short Recordings
        ↓
Medium Recordings
        ↓
Long Recordings
        ↓
Stress Testing
        ↓
Backend Analysis
```

---

# Long-Duration Testing

Extended-duration testing helps evaluate:

* SD card stability,
* memory behavior,
* backend consistency,
* upload recovery,
* and transcription reliability.

Recommended durations:

* 15 minutes,
* 30 minutes,

---

# Additional Resources

## Google Sheets Documentation

* [Google Sheets Documentation](https://support.google.com/docs?utm_source=chatgpt.com)

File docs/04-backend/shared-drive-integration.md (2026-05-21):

# Shared Drive Setup Guide

This section documents how to configure Google Shared Drive integration for the Audionote system.

The Shared Drive integration enables:

* centralized lecture archival,
* collaborative access,
* automated transcript organization,
* and long-term cloud accessibility.

At the end of this section, you should have:

* a working Google Workspace environment,
* a configured Shared Drive,
* proper folder structures,
* backend integration access,
* and automated transcript archival readiness.

---

# Why Shared Drive Integration Exists

Audionote is designed not only to:

* record lectures,
* and generate transcripts,

but also to:

* organize educational content automatically,
* simplify lecture accessibility,
* and improve collaboration between users.

Google Shared Drive was selected because it:

* supports collaborative file ownership,
* integrates well with Google APIs,
* supports large-scale organization,
* and is widely accessible in academic environments.

---

# Shared Drive Architecture Overview

```text id="qbpjlwm"
ESP32 Device
        ↓
Cloud Upload
        ↓
Transcription Backend
        ↓
Google Shared Drive
        ↓
Automated Folder Organization
```

---

# Before You Begin

Ensure the following stages are already completed:

* Firmware setup
* Hardware assembly
* Backend deployment
* Cloud Storage setup
* Transcription backend validation

Continue from:

→ [Backend Deployment Guide](deployment-guide.md)

or

→ [GUI Backend Deployment Guide](deployment-gui-based.md)

---

# Recommended Requirements

| Requirement | Purpose |
| --- | --- |
| Google Workspace Account | Shared Drive support |
| Custom Domain Name | Workspace setup |
| Google Cloud Project | API integration |
| Google Drive API Enabled | Backend integration  |

---
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

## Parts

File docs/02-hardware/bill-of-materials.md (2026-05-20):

# Bill of Materials

| Part | Description | Image | Qty | Notes |
| --- | --- | --- | --- | --- |
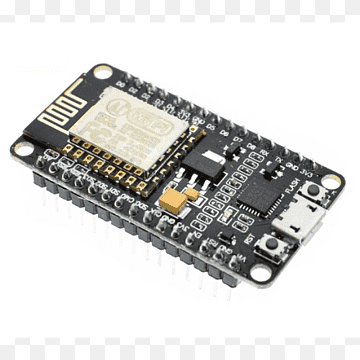
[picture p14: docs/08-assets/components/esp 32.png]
| ESP32 DevKitC | Main embedded controller |   | 1 | ESP32-WROOM-32D was used in this project, primarily because of innate I2S support |
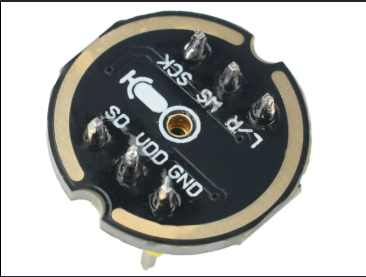
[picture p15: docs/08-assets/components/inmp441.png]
| INMP441* | Digital I2S MEMS microphone |  | 1 | Preferably get the version with pre-soldered header pins. To get these, I recommend you order it from [Microscale](https://www.microscale.net/products/inmp441-omnidirectional-microphone-module?_pos=1&_sid=2cc91557d&_ss=r) for builders in Nigeria. |
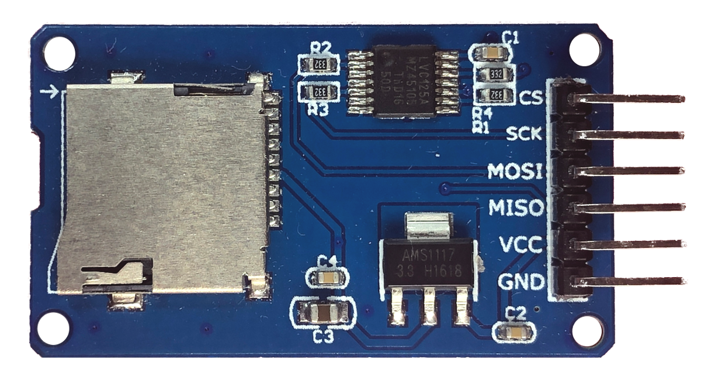
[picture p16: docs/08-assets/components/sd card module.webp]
| MicroSD Module* | Local audio storage interface |  | 1 | FAT32 recommended |
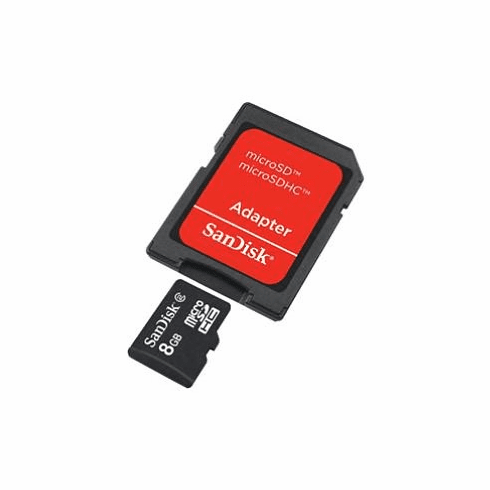
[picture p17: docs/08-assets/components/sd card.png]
| MicroSD Card | Audio recording storage |  | 1 | ≥ 4GB recommended; adapter version helps with debugging and file extraction | |
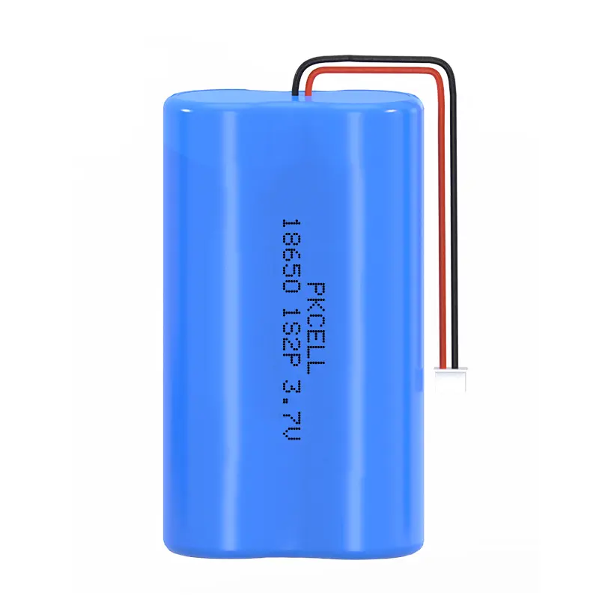
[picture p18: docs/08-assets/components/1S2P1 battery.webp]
| 18650 Cells | Battery cells used in battery assembly |  | 2 | Used in parallel battery, 3.7V configuration |
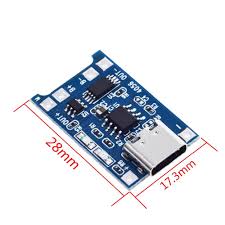
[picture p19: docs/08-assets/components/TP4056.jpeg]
| TP4056 Module* | Battery charging module |  | 1 | USB charging with protection circuitry |
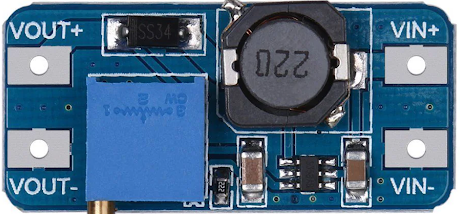
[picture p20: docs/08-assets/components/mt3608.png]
| MT3608 Boost Converter | Voltage step-up converter |  | 1 | Used for regulated voltage supply |
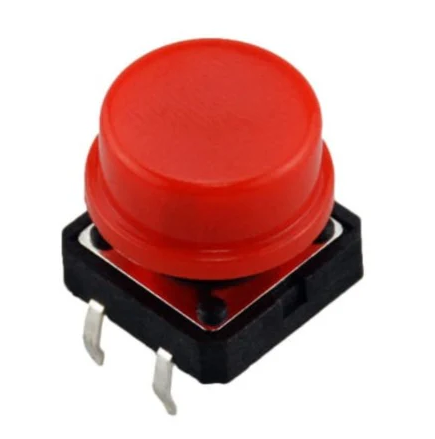
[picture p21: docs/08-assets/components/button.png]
| Push Button | Recording control |  | 1 | Used for recording start/stop control |
| Power Switch | Main power control switch |  | 1 | Used for isolating battery power |
| Vero Board | Prototype circuit mounting board |  | 1 | Small dotted Vero board used for prototyping |
| Female Pin Headers* | Modular pin connections |  | 2 19-pin headers | Additional bent headers cam also be utilized |
| Jumper Wires | Interconnections between modules |  | Multiple | Includes male-female, male-male, and female-female jumper wires |
| Hook-up Wires | Power and signal wiring |  | Multiple | Recycled phone and PC wires were also utilized |
| Spring Connectors | Wire joining and modular connection |  | Multiple | Useful for temporary secure connections |
| 470uF Capacitor* | Voltage stabilizer, transient buffer |  | 1 | |
| Heat Shrink Tubing | Electrical insulation and cable management |  | Multiple small sizes (optional) | Used for battery and wire insulation |
| Velcro Strap | Portable mounting system |  | 1 | Used for wearable/portable deployment |
| Zip Ties | Cable management and internal fastening |  | Multiple | Used for internal enclosure organization |
| Enclosure | Device housing |  | 1 | Double socket pattress used in prototype stage; 3D printable enclosure also available |
| 3D Printed Enclosure | Custom enclosure system |  | 1 | Optional final enclosure design |
| Bag Material | Portable carrying/mounting accessory |  | 1 | Used for wearable deployment concept |
| Buckle | Portable carrying/mounting accessory |  | 1 | Used for wearable deployment concept |
| Soldering Lead | Soldering material |  | Multiple | Used for permanent electrical connections |
| Glue Sticks | Hot glue application material |  | Multiple | Used for internal fastening and insulation |

- Apart from materials like Jumper wires, soldering lead, which usually need to be bought in multiples, I recommend buying (at least) 2-3 of the materials that have been starrred (*). I found these particlar components to be particularly tricky. More in the hardware documentation.
  
- I also recommend buying extra components, that are usually cheaper and more prone to error than the microcontrollers, as good prcatice for any hardware/embedded systems project.

# Other Equipment

These items were utilized during development, prototyping, testing, and assembly but are not part of the final deployed device.

| Equipment | Purpose | Notes |
| --- | --- | --- |
| Glue Gun | Component mounting and enclosure fastening  | Used extensively during prototyping |
| Hand Drill | Enclosure modification and mounting holes | Used for pattress and enclosure customization |
| Cutter with Extra Blades | Wire stripping and enclosure cutting | Useful for precision modifications |
| Soldering Iron | Electronic assembly and soldering | Required for permanent hardware assembly |
| USB Cable | ESP32 programming and debugging | USB data cable recommended |
| Computer/Laptop | Firmware development and backend deployment | Used for Arduino IDE and cloud setup |
| SD Card Adapter/Dongle | SD card debugging and file transfer | Useful for extracting recordings directly |
| Multimeter | Voltage and continuity testing | Important during power system debugging |
| USB Cord | Firmware development and system debugging | Important during system debugging; Either Type B or Type C depending on your ESP 32 dev board connector pin |
| Breadboard | Initial prototyping and testing | Optional but highly recommended |

# Software Purchases & Cloud Services

These services and software-related resources were utilized as part of the Audionote backend infrastructure and deployment workflow.

| Service / Software | Purpose | Notes |
| --- | --- | --- |
| Google Workspace Subscription | Shared Drive infrastructure and institutional file organization | Required for structured archival workflow |
| Domain Name | Custom domain configuration for backend/cloud services | Used for platform branding and service configuration |
| Google Cloud Platform (GCP) (Free credits available) | Cloud backend hosting and infrastructure | Includes Cloud Run, Storage, IAM, APIs, etc. You can get this for free on a new account. See Backend documentation for more details. |
| Arduino IDE (Free) | ESP32 firmware development | Main embedded firmware environment |
| SolidWorks/ CAD Software (Optional)  | 3D enclosure modeling | Used for enclosure development workflow |

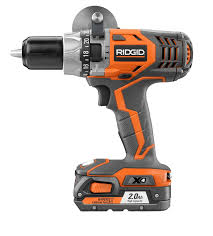
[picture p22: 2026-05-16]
docs/08-assets/components/hand drill.jpg

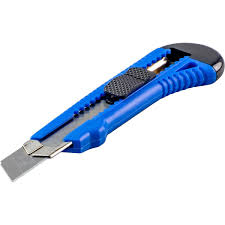
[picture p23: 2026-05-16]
docs/08-assets/components/cutter.jpg

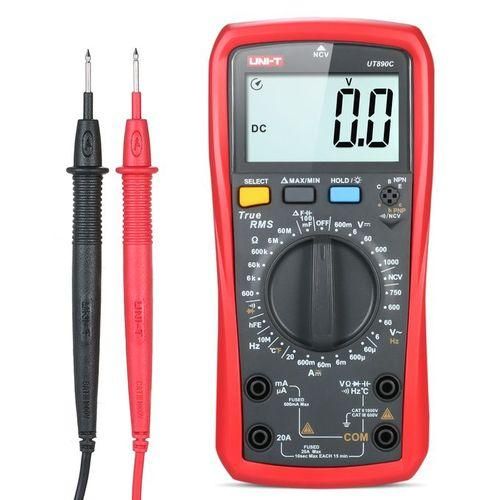
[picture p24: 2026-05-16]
docs/08-assets/components/multimeter.jpg

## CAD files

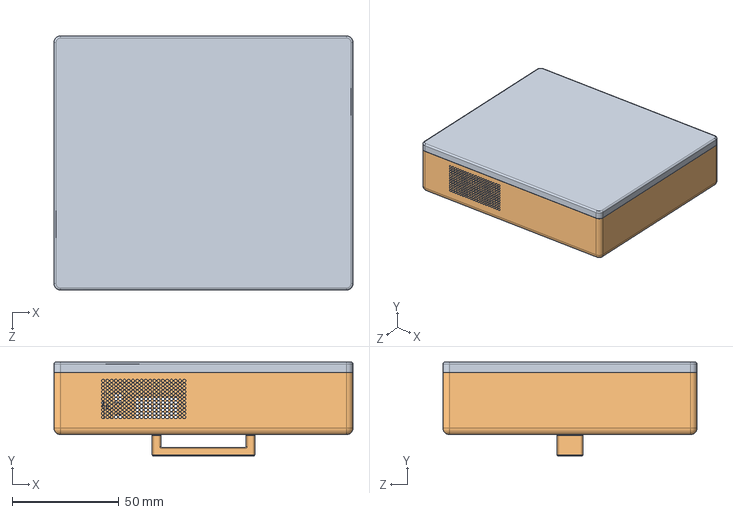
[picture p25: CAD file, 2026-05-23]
hardware/enclosure/Assembly.SLDASM
140.0 x 44.0 x 119.0 mm
Base
Top Cover

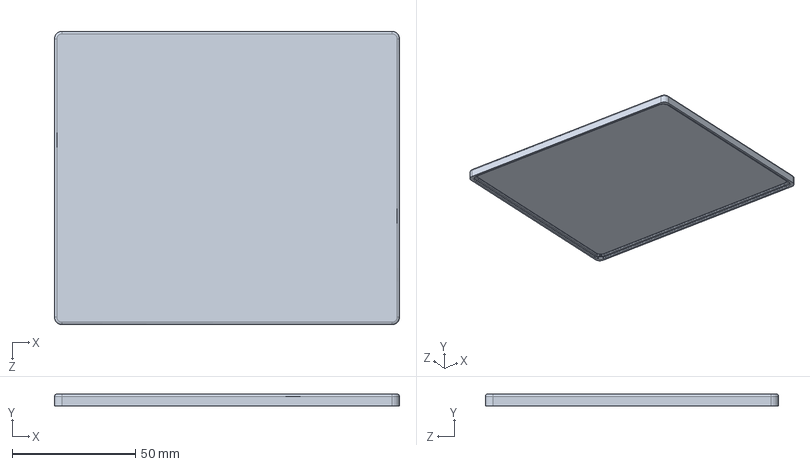
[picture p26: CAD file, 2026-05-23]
hardware/enclosure/Top Cover.SLDPRT
140.0 x 4.90 x 119.0 mm

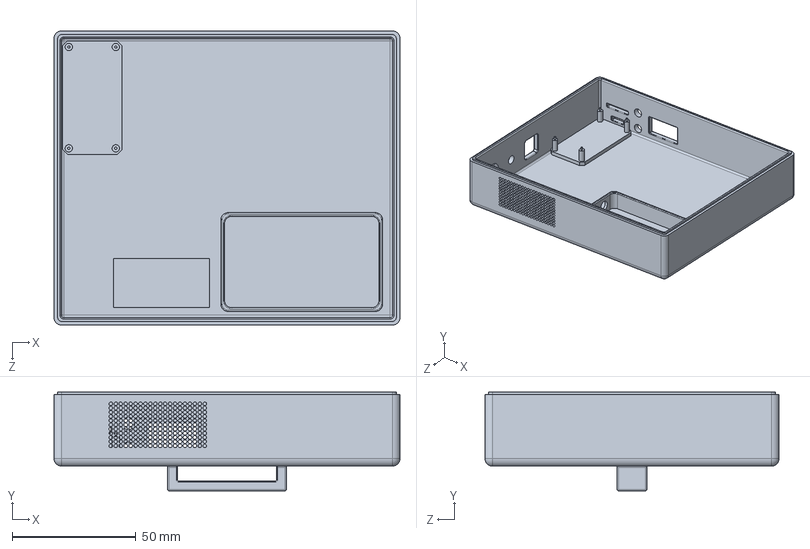
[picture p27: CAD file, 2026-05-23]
hardware/enclosure/Base.SLDPRT
140.0 x 39.9 x 119.0 mm

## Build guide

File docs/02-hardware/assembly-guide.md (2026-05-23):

# Hardware Assembly Guide

This section walks through the physical hardware integration process for the Audionote embedded lecture transcription system.

Make sure to read through each build instructions (at least) one stage after another before implementing the build instructions in order to avoid damaging components.

The assembly workflow is intentionally divided into incremental validation stages to:

* simplify debugging,
* isolate subsystem failures,
* reduce wiring complexity,
* and improve development reliability.

Rather than assembling the entire system at once, each major subsystem is validated independently before moving to the next integration stage.

At the end of this section, you should have:

* a fully operational audio acquisition system,
* local WAV recording capability,
* validated upload functionality,
* and a stable hardware platform ready for power system integration and enclosure deployment.

---

# Hardware Integration Workflow

```text id="xz6h9s"
ESP32 Validation
        ↓
Microphone Integration
        ↓
Audio Capture Testing
        ↓
SD Card Integration
        ↓
WAV Recording Validation
        ↓
Wi-Fi Upload Validation
        ↓
Core System Stability Testing
        ↓
Power System Integration
        ↓
Final Enclosure Assembly
```

---

# Before You Begin

Ensure you have completed:

* Firmware setup
* ESP32 board validation
* Firmware upload verification

Continue from:

→ [Firmware Setup](../03-firmware/esp32-setup.md)

---

# Required Hardware

Ensure all required components from the BOM are available before proceeding.

Continue to:

→ [Bill of Materials](bill-of-materials.md)

---

# Recommended Tools

| Tool | Purpose |
| --- | --- |
| Soldering Iron | Permanent electrical connections |
| Glue Gun | Internal component mounting |
| Wire Cutter/Stripper  | Cable preparation |
| Multimeter | Voltage and continuity testing |
| Breadboard | Temporary prototyping |
| SD Card Adapter | File debugging and extraction |
| USB Cable | ESP32 programming and power |

---

# Initial Device Development Image

Initial Device Development

---

# Stage 1 — ESP32 Base Validation

Before connecting additional modules, first validate the ESP32 independently.

## Objectives

Validate:

* firmware upload,
* serial communication,
* stable boot operation,
* and Wi-Fi initialization.

---

## Steps

1. Connect the ESP32 to your computer
2. Upload the firmware
3. Open Serial Monitor
4. Verify initialization logs

Expected output:

```text id="zw7vwo"
System Boot Successful
WiFi Initialized
Awaiting Hardware Initialization
```

---

# Validation Checkpoint

| Test | Expected Result |
| --- | --- |
| ESP32 powers on | Successful |
| Serial monitor output | Stable |
| No reboot loops | Stable |
| Wi-Fi initialization  | Successful |

---

# Common Issues

| Problem | Possible Cause | Suggested Fix |
| --- | --- | --- |
| Continuous rebooting | Insufficient USB power | Use better USB source |
| ESP32 not detected | Faulty USB cable | Replace with data cable |
| Upload failures | Wrong COM port | Re-select correct port  |

---

# Stage 2 — INMP441 Microphone Integration

The INMP441 is the primary audio acquisition component of the system.

Audionote uses the ESP32 I2S peripheral to receive digital audio from the microphone.

---

# INMP441 Wiring

## Recommended Wiring Diagram

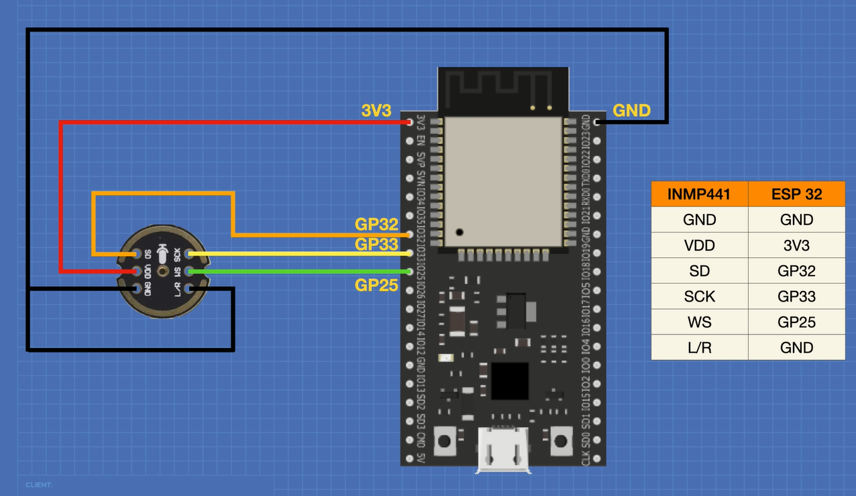
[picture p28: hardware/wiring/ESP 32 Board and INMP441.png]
INMP441 Wiring


Source: [DroneBot Workshop](https://dronebotworkshop.com/esp32-i2s/)

| INMP441 Pin | ESP32 Pin |
| --- | --- |
| VCC | 3.3V |
| GND | GND |
| WS | GPIO 25 |
| SCK | GPIO 32 |
| SD | GPIO 33 |
| L/R | GND |

Verify your firmware pin configuration matches the physical wiring.

---

# I2S Documentation

* [ESP32 I2S Peripheral Documentation](https://docs.espressif.com/projects/esp-idf/en/latest/esp32/api-reference/peripherals/i2s.html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)

---

# Important Microphone Notes

* Use short wires where possible (for initial development).
* Utilize just the esp 32 microcontroller and INMP441 mic setup on the breadboard with jumper wires connecting the metal ends in the breadboard for inital development like in the development demo image shown above.
* I noticed that the INMP441 microphone sometimes wasn't outputting the right data, despite verifying that the right connections were made and continuity. I found that tying the microphone connection wires together closely solved this.
* Many jumper wires in the collections don't work well. Test for continuity before use them in your connections, especially the permanent ones.
* Avoid running audio lines near noisy power wiring
* Ensure stable 3.3V supply
* Ground integrity is extremely important for clean audio
* Avoid changing the wiring while the microphone is powered as this can lead to a short.
  P.S.: I learned this lesson (and other ones) after my third microphone got damaged.
* Also, avoid touching the metal ends of the microphone when it's being powered from your esp 32 board as this can also cause shorts. Better to be safe than sorry. The price of the mics stack up as you have to purchase additional ones.
* As mentioned in the [Bill of Materials](bill-of-materials.md), it's very adviced to purchase only the INMP441 mics that come with their metal ends already soldered. i damaged 2 of my first microhphones from the heat of the soldering iron while trying to solder them on propoerly (and it's not because I'm bad at soldering.) 🙃

---

# Audio Capture Test

After connecting the microphone:

1. Upload firmware
2. Start recording
3. Stop recording
4. Verify WAV file generation

Expected result:

* WAV file successfully created on SD card (later stage)
* Serial logs indicate active audio sampling

---

# Validation Checkpoint

| Test | Expected Result |
| --- | --- |
| I2S initialization | Successful |
| Audio capture starts | Successful |
| No major noise/distortion | Stable |
| No ESP32 crashes | Stable |

---

# Common Issues

| Problem | Possible Cause | Suggested Fix |
| --- | --- | --- |
| No audio data | Incorrect wiring | Verify I2S pin mapping |
| Distorted audio | Ground instability | Improve grounding |
| Very low audio  | Incorrect gain/config | Verify firmware configuration |
| ESP32 freeze | Incorrect DMA configuration | Verify buffer settings |

---

# Audio Waveform Test Code

As you try to get the INMP441 mic to work, you may (most likely) face problems ensuring that your connections are secure and that the audio is actually being captured.

To test and ensure that your mic is working well and performing as it ought to:
* Download the [INMP441 test code](/firmware/tests/microphone_test/DroneBot_INMP441_File.ino) (courtesy of DroneBot Workshop).
* Upload it to your ESP 32 board
* Open your Serial Plotter to see the output waveform.

Source: [DroneBot Workshop](https://dronebotworkshop.com/esp32-i2s/)

## Correct Audio Waveform Test Diagram

The correct audio waveform for a silent room is shown below:

Correct audio wave for silence

Note:

* You would see frequency spikes as you speak into the mic and it will return back to a waveform similar to the one above when no there is no audio input.
* If your audio waveform is not very similar to this, check your connections.
* Upload your main esp32 setup firmware code back when you've ensured that the INMP441 microphone is capturing the audio data as it ought to.

---

# Stage 3 — SD Card Module Integration

The SD card subsystem provides persistent local storage for recorded lecture audio.

This is one of the most important reliability features of Audionote.

---

# SD Card Wiring

| SD Module Pin | ESP32 Pin |
| --- | --- |
| VCC | 5V |
| GND | GND |
| MISO | GPIO 19 |
| MOSI | GPIO 23 |
| SCK | GPIO 18 |
| CS | GPIO 5 |

---

# SD Card Formatting

Before use:

* Format the SD card as FAT32

Recommended:

* Class 10 SD cards
* ≥ 4GB storage

Useful formatting guide:

* [SD Card Formatter Utility](https://www.sdcard.org/downloads/formatter/?utm_source=chatgpt.com)

---

# SD Card Validation

After integration:

1. Insert SD card
2. Power the ESP32
3. Observe serial logs

Expected output:

```text id="58o7x9"
Initializing SD card...
SD card mounted successfully
```

---

# WAV Recording Validation

Perform a short recording test.

Validate:

* file creation,
* file size growth,
* and audio playback.

Recommended:

* Remove SD card
* Play WAV file on a computer

Expected result:

* intelligible speech recording

---

# Validation Checkpoint

| Test | Expected Result |
| --- | --- |
| SD card mount | Successful |
| WAV file creation  | Successful |
| Audio playback | Intelligible |
| No file corruption | Stable |

---

# Common Issues

| Problem | Possible Cause | Suggested Fix |
| --- | --- | --- |
| SD mount failed | Incorrect formatting | Reformat FAT32 |
| Corrupted WAV file | Improper shutdown | Stop recording properly |
| Recording stops randomly | Power instability | Improve power delivery  |
| No files created | Incorrect CS pin | Verify SPI wiring |

---

# Important SD Card Module Notes

* Strictly avoid hot wiring the SD Card while it is being powered. Hot-wiring or pulling an SD card while it is powered poses severe risks to your hardware and data. The practice bypasses safe hardware handshakes and can trigger critical faults.
*  The module may briefly pause operation after several write cycles while the SD card's internal controller erases flash pages. When tis occurs, briefly stop testing or replace with another SD Card module.
*  Make sure the (temporary) jumper connections are good and tight as the pins of the SD card module are sensitive. If not connected well, audio files would be corrupted.
*  After full assembly, I noticed that I needed to scratch between the SD card solder connection lines on the main veroboard. I think this is due to cross-talk of the SD communication lines even though I verified zero continuity between the soldering connection lines.

---

# Stage 4 — Wi-Fi Upload Validation

Once local recording is validated, test cloud upload functionality. To do this, you have to set up your backend GCF endpoint which can be seen in [Backend Deployment Guide](../04-backend/deployment-guide.md).

---

# Objectives

Validate:

* Wi-Fi connectivity,
* backend communication,
* chunk upload handling,
* and successful upload completion.

---

# Upload Validation Procedure

1. Connect to Wi-Fi
2. Record short audio sample
3. Stop recording
4. Wait for upload sequence

Expected serial output:

```text id="utrz6o"
WiFi connected
Requesting signed upload URL...
Upload session initialized
Uploading chunks...
Upload completed successfully
```

---

# Validation Checkpoint

| Test | Expected Result |
| --- | --- |
| Wi-Fi connection | Successful |
| Signed URL generation | Successful |
| Upload begins | Successful |
| Upload completes | Successful |

---

# Common Issues

| Problem | Possible Cause | Suggested Fix |
| --- | --- | --- |
| Wi-Fi timeout  | Weak signal | Improve signal quality |
| Upload failure | Backend unavailable | Verify backend deployment |
| HTTPS error | Invalid endpoint | Verify URL configuration  |
| Upload stalls  | Oversized chunks | Reduce chunk size |

---

# Stage 5 — Core System Stability Testing

Before integrating the power subsystem, validate the complete recording pipeline under repeated usage.

---

# Recommended Stability Tests

## Recording Loop Test

Perform:

* multiple consecutive recordings,
* repeated upload cycles,
* and extended runtime validation.

---

## Long Recording Test

Validate:

* SD stability,
* memory usage,
* and upload integrity.

Recommended:

* ≥ 15 minute recordings

---

## Brownout Observation Test

Watch for:

* unexpected ESP32 resets,
* SD corruption,
* upload interruptions,
* or unstable Wi-Fi behavior.

---

# Stability Validation Checklist

| Test | Expected Result |
| --- | --- |
| Multiple recordings | Stable |
| Long-duration recording | Stable |
| Repeated uploads | Stable |
| No unexpected resets | Stable |
| No file corruption | Stable |

---

# Recommended Next Step

Once the core recording and upload pipeline is validated successfully, proceed to portable power integration.

Continue to:

→ [Power System Documentation](power-system.md)

Then:

→ [Backend Deployment Guide](../04-backend/deployment-guide.md)

---

# Additional Resources

## ESP32 Documentation

* [ESP32 Documentation by Espressif](https://docs.espressif.com/projects/esp-idf/en/latest/esp32/?utm_source=chatgpt.com)

## SPI Documentation

* [Arduino SPI Documentation](https://www.arduino.cc/en/reference/SPI?utm_source=chatgpt.com)

## SD Library Documentation

* [Arduino SD Library Documentation](https://docs.arduino.cc/libraries/sd/?utm_source=chatgpt.com)

## FAT32 Formatting Utility

* [Official SD Card Formatter Utility](https://www.sdcard.org/downloads/formatter/?utm_source=chatgpt.com)

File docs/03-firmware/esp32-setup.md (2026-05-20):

# Firmware Setup

This section guides you through setting up the embedded firmware development environment for Audionote.

The objective of this stage is to:

* prepare the ESP32 firmware toolchain,
* install all required dependencies,
* configure the development environment,
* validate firmware upload capability,
* and confirm that the ESP32 board can communicate successfully with your computer before hardware integration begins.

At the end of this section, you should be able to:

* upload firmware to the ESP32,
* monitor serial output,
* and begin incremental hardware integration safely.

---

# Firmware Development Workflow

```text
Install Arduino IDE
        ↓
Install ESP32 Board Package
        ↓
Install Required Libraries
        ↓
Download the Firmware Folder
        ↓
Configure Firmware
        ↓
Connect ESP32
        ↓
Upload Firmware
        ↓
Validate Serial Output
        ↓
Proceed to Hardware Integration
```

---

# Requirements

Before proceeding, ensure you have the following:

| Requirement | Purpose |
| --- | --- |
| Computer/Laptop | Firmware development and flashing |
| USB Data Cable | ESP32 communication and programming |
| ESP32 DevKitC Board | Main embedded controller |
| Internet Connection | Library and board package installation |
| Arduino IDE | Firmware development environment |

---

# 1. Install Arduino IDE

Audionote firmware development is based primarily on the Arduino framework for ESP32.

Download and install the latest version of the Arduino IDE:

* [Arduino IDE Download Page](https://www.arduino.cc/en/software?utm_source=chatgpt.com)

Recommended:

* Arduino IDE 2.x or newer

After installation:

1. Launch Arduino IDE
2. Confirm the IDE opens successfully
3. Proceed to ESP32 board installation

---

# 2. Install ESP32 Board Support Package

The ESP32 board package adds support for ESP32 development boards within the Arduino IDE.

## Add ESP32 Board Manager URL

Open:

```text
File → Preferences
```

Inside the:

```text
Additional Boards Manager URLs
```

field, add:

```text
https://raw.githubusercontent.com/espressif/arduino-esp32/gh-pages/package_esp32_index.json
```

Official ESP32 Arduino setup guide:

* [ESP32 Arduino Core Installation Guide](https://docs.espressif.com/projects/arduino-esp32/en/latest/installing.html?utm_source=chatgpt.com)

---

## Install ESP32 Package

Open:

```text
Tools → Board → Boards Manager
```

Search for:

```text
ESP32
```

Install:

```text
esp32 by Espressif Systems
```

Recommended:

* Install the 3.3.1 version. I found that the newer versions didn't have good enough i2s support.

---

# 3. Configure the ESP32 Board

After installation:

Open:

```text
Tools → Board
```

Select:

```text
ESP32 Dev Module
```

or the equivalent DevKitC board option available in your installed package version.

Recommended settings:

| Setting | Value |
| --- | --- |
| Flash Frequency  | 80MHz |
| Upload Speed | 921600  |
| Partition Scheme | Default |
| Core Debug Level | None |

---

# 4. Install Required Libraries

Audionote uses several libraries for:

* Wi-Fi communication,
* SD card storage,
* JSON handling,
* HTTPS communication,
* and audio processing.

## Install Libraries via Library Manager

Open:

```text
Sketch → Include Library (You'd see all already installed libraries here) → Manage Libraries
```

Install the following:

| Library | Purpose |
| --- | --- |
| ArduinoJson | JSON serialization/deserialization |
| FS | File system access |
| SD | SD card filesystem |
| SPI | SPI communication |
| WiFi | Wireless connectivity |
| HTTPClient | HTTPS uploads |
| WiFiClientSecure | Secure HTTPS communication |

---
Note:
* Most of the libraries listed above come automatically bundled with the ESP32 Arduino Core, except for the ArduinoJson library. You can see them in Sketch → Include Library.
* If they aren't there, you may have to reinstall the esp 32 board manager or try searching and installing them individually from the Library Manager 📚.
* The i2s support driver is bundled in the ESP-IDF core. You do not need to install anything externally.

## ArduinoJson Installation

Official documentation:

* [ArduinoJson Documentation](https://arduinojson.org/?utm_source=chatgpt.com)

Recommended:

* Use the latest stable release.

---

# 5. Install USB Drivers (If Necessary)

Some ESP32 boards require USB-to-serial drivers depending on the onboard USB chip.

Common USB bridge chips include:

| Chip | Driver |
| --- | --- |
| CP2102 | Silicon Labs Driver |
| CH340  | WCH Driver |

## CP210x Driver

* [CP210x USB Driver Download](https://www.silabs.com/developers/usb-to-uart-bridge-vcp-drivers?utm_source=chatgpt.com)

## CH340 Driver

* [CH340 Driver Download](https://sparks.gogo.co.nz/ch340.html?utm_source=chatgpt.com)

After installation:

1. Reconnect the ESP32
2. Verify a COM port appears in Arduino IDE

---

# 6. Download the Firmware Folder

Download the folder [here](/firmware)

Open:

```text
firmware/audionote/audionote.ino
```

inside Arduino IDE.

---

# 7. Configure Firmware Variables

Before uploading firmware, configure:

* Wi-Fi credentials,
* backend endpoint URLs,
* API configuration values,
* and device-specific settings.

---

## Example Wi-Fi Configuration

```cpp
const char *ssid = "YOUR_WIFI_NAME";
const char *password = "YOUR_WIFI_PASSWORD";
```
Replace the placeholders with your WiFi credentials.

---

## Example Backend Configuration

```cpp
#define SIGNED_URL_ENDPOINT "https://your-backend-url.com" // Your GCF endpoint
```
Don't worry about this yet as you haven't set up your backend infrastructure.

---

## Example Course Info Configuration

```cpp
const char *COURSE_CODE = "COURSE_CODE eg., EEE313";
const int COURSE_LEVEL = YEAR_OF_STUDY eg., 300, 100;  // This must be an integer, and not include letters.
const char *DEVICE_ID = "esp32a1";
```

It isn't necssary to change the details here. This basically handles the file organization in the final Shared Drive Folder. It classifies the lectures in an institution according to the course code, year of study being instructed, and unique device id of the esp 32 device used to process the specific lecture.

---

# 8. Connect the ESP32 Board

Using a USB data cable:

1. Connect the ESP32 board to your computer
2. Wait for device detection
3. Open Arduino IDE

Select the correct COM port:

```text
Tools → Port
```

---

# 9. Upload Firmware

Click:

```text
Upload
```

or use:

```text
Ctrl + U
```

The firmware should now compile and upload to the ESP32.

During upload:

* the ESP32 bootloader initializes,
* firmware is flashed,
* and the device automatically reboots.

---

# 10. Open Serial Monitor

After successful upload:

Open:

```text
Tools → Serial Monitor
```

Recommended baud rate:

```text
115200
```

Expected output should include initialization logs similar to:

```text
Initializing SD card...
SD card mounted successfully

Connecting to WiFi...
WiFi connected

System ready
```
Don't worry if the log reads failure at some points here, as you (most likely) haven't set up your backend and hardware systems. The essential thing is that your code uploaded.

---

# Firmware Validation Checkpoint

Before proceeding to hardware integration, validate the following:

| Validation Item | Expected Result |
| --- | --- |
| Firmware Upload | Successful |
| Serial Monitor Output | Readable logs |
| ESP32 Boot | Stable |
| Wi-Fi Initialization  | Successful |
| SD Initialization | No errors |
| No Continuous Reboots | Stable runtime  |

---

# Common Firmware Setup Issues

| Problem | Possible Cause | Suggested Fix |
| --- | --- | --- |
| ESP32 not detected | Faulty USB cable | Use a USB data cable |
| Upload failed | Wrong COM port | Re-select correct port |
| Board not recognized | Missing drivers | Install USB drivers |
| Continuous rebooting | Power instability | Use stable USB power |
| Missing libraries | Library installation incomplete | Reinstall required libraries |
| Compilation failure  | ESP32 package mismatch | Update board package |

---

# Recommended Next Step

Once firmware upload and serial communication are validated successfully, proceed to component acquisition and incremental hardware integration.

Continue to:

→ [Bill of Materials](../02-hardware/bill-of-materials.md)

Then:

→ [Hardware Assembly Guide](../02-hardware/assembly-guide.md)

---

# Additional Resources

## ESP32 Documentation

* [ESP32 Documentation by Espressif](https://docs.espressif.com/projects/esp-idf/en/latest/esp32/?utm_source=chatgpt.com)

## Arduino IDE Documentation

* [Arduino IDE Documentation](https://docs.arduino.cc/software/ide-v2/tutorials/getting-started/ide-v2-downloading-and-installing/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)

## ESP32 Arduino GitHub Repository

* [ESP32 Arduino GitHub Repository](https://github.com/espressif/arduino-esp32?utm_source=chatgpt.com)

## I2S Peripheral Documentation

* [ESP32 I2S Peripheral Documentation](https://docs.espressif.com/projects/esp-idf/en/latest/esp32/api-reference/peripherals/i2s.html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)

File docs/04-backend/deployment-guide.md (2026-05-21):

# Backend Deployment Guide (CLI-heavy)

This section documents the deployment and configuration workflow for the Audionote cloud backend infrastructure.

The backend system is responsible for:

* generating secure upload URLs,
* receiving uploaded lecture recordings,
* triggering automatic transcription,
* organizing recordings,
* and integrating with Google Shared Drive for archival.

Audionote primarily uses:

* Google Cloud Run,
* Google Cloud Storage,
* Google Speech-to-Text,
* Google Drive API,
* and Google Workspace infrastructure.

At the end of this section, you should have:

* a deployed cloud backend,
* working upload endpoints,
* automated transcription processing,
* and a validated storage pipeline ready for Shared Drive integration.

---

# Backend Architecture Overview

```text id="g8ny8p"
ESP32 Device
        ↓
Signed URL Backend
        ↓
Google Cloud Storage
        ↓
Auto-Transcription Service
        ↓
Google Speech-to-Text
        ↓
Google Shared Drive
```

---

# Before You Begin

Ensure the following stages are already completed:

* Firmware setup
* Hardware assembly
* Audio recording validation
* Upload system validation
* Power system integration

Continue from:

→ [Power System Guide](../02-hardware/power-system.md)

---

# Backend Components

| Service | Purpose |
| --- | --- |
| Cloud Run | Backend service hosting  |
| Cloud Storage | Audio file storage |
| Speech-to-Text API | Audio transcription |
| Google Drive API | Shared Drive integration |
| IAM | Access management |
| Cloud Logging | Monitoring and debugging |

---

# Recommended Knowledge

Basic familiarity with:

* JavaScript/Node.js,
* terminal usage,
* and Google Cloud Platform

is recommended. I got by with none so don't worry. 😃

---

# Google Cloud Free Credits for New Accounts

Google Cloud typically provides free credits for new accounts which can be used during development and testing.

At the time of writing, new users may receive promotional credits after:
- creating a Google Cloud account,
- enabling billing,
- and verifying payment information.

This is usually sufficient for:
- Cloud Run deployment,
- Storage usage,
- Speech-to-Text testing,
- and backend experimentation during development.

Learn more:

- :contentReference[oaicite:0]{index=0}

---

# Important Note About Billing

Even when using free credits:

- billing must still be enabled,
- APIs may still require activation,
- and usage limits still apply.

To avoid unexpected charges:
- monitor usage regularly,
- configure billing alerts,
- and test with short recordings initially.

---

# Stage 1 — Create a Google Cloud Project

Create a new Google Cloud project.

Open:

* [Google Cloud Console](https://console.cloud.google.com/?utm_source=chatgpt.com)

---

# Create a New Project

1. Open the Google Cloud Console
2. Click project selector
3. Create a new project
4. Give the project a name

Example:

```text id="0llc5p"
audionote-backend
```

---

# Enable Billing

Cloud Run and Speech-to-Text require billing to be enabled.

Billing setup:

* [Google Cloud Billing Setup Guide](https://cloud.google.com/billing/docs/how-to/modify-project?utm_source=chatgpt.com)

---

# Stage 2 — Install Google Cloud CLI

Install the Google Cloud SDK locally.

Official installation guide:

* [Google Cloud CLI Installation Guide](https://cloud.google.com/sdk/docs/install?utm_source=chatgpt.com)

---

# Verify Installation

Run:

```bash id="nq3d2l"
gcloud --version
```

Expected output:

* installed SDK version information

---

# Authenticate Locally

Run:

```bash id="drm2c4"
gcloud auth login
```

Then:

```bash id="djlwm4"
gcloud config set project YOUR_PROJECT_ID
```

Replace the place holder with your project ID. You can find this in your project selector or even i the CLI.

---

# Stage 3 — Enable Required APIs

Enable the following APIs:

| API | Purpose |
| --- | --- |
| Cloud Run API | Backend hosting |
| Cloud Storage API  | File storage |
| Speech-to-Text API | Audio transcription |
| Drive API | Shared Drive automation |
| IAM API | Permission management |

---

# Enable APIs Using CLI

Run:

```bash id="4n2cn0"
gcloud services enable run.googleapis.com
```

```bash id="t1d7l4"
gcloud services enable speech.googleapis.com
```

```bash id="7g0btx"
gcloud services enable storage.googleapis.com
```

```bash id="v8r9m4"
gcloud services enable drive.googleapis.com
```

```bash id="3k6kbo"
gcloud services enable iam.googleapis.com
```

---

# Additional API Setup Reference

* [Google Cloud API Enablement Guide](https://cloud.google.com/apis/docs/getting-started?utm_source=chatgpt.com)

---

# Stage 4 — Create Cloud Storage Bucket

The storage bucket stores uploaded WAV recordings before transcription processing.

---

# Create Bucket

Open:

* [Google Cloud Storage Console](https://console.cloud.google.com/storage?utm_source=chatgpt.com)

Create a new bucket.

Example naming:

```text id="3xjzj9"
audionote-recordings
```

---

# Recommended Bucket Settings

| Setting | Recommendation |
| --- | --- |
| Access Control | Uniform |
| Location Type  | Region |
| Storage Class  | Standard |

---

# Bucket Structure Recommendation

```text id="2e5u1m"
lectures/
    └── level/
          └── course/
                └── recording-session/
```

---

# Stage 4.5 — Obtain the Backend Source Code

Before deployment, ensure the Audionote backend source code is available locally.

You can either:

- clone the full repository,
- or download the repository ZIP or specific files/folders from GitHub.

---

# Clone the Repository

```bash
git clone https://github.com/Ayoo5/audionote
```

Then navigate into the repository:

```bash
cd audionote
```

---

# Alternative: Manual Backend File Upload

If you do not want to clone the full repository, you can manually download the backend folders and upload them into your Google Cloud environment.

Required backend folders:

```text
backend/
├── signedurl/
└── autotranscribe/
```

Each folder should contain:

```text
index.js
package.json
```

and any additional configuration files used in the project.

---

# Recommended Upload Methods

## Option 1 — Upload Using Google Cloud Shell

Open:

* [Google Cloud Shell](https://console.cloud.google.com/cloudshell?utm_source=chatgpt.com)

Then:

1. Create backend directories:

```bash
mkdir -p backend/signedurl
mkdir -p backend/autotranscribe
```

2. Upload files manually using the Cloud Shell upload button

3. Verify uploaded files:

```bash
ls backend/signedurl
ls backend/autotranscribe
```

---

## Option 2 — Upload Using Cloud Shell Editor

Open:

* [Google Cloud Shell](https://console.cloud.google.com/shell?utm_source=chatgpt.com)

Then:

1. Open the Cloud Shell Editor
2. Create backend folders manually
3. Drag and drop the backend files into the editor workspace
4. Open terminal and install dependencies

---

# Recommended Validation

Before deployment, verify:

| Validation Item | Expected Result |
|---|---|
| index.js exists | Yes |
| package.json exists | Yes |
| npm install completes | Successful |
| No missing dependencies | Successful |

---

# Backend Directory Structure

```text
backend/
├── signedurl/
│     ├── index.js
│     └── package.json
│
└── autotranscribe/
      ├── index.js
      └── package.json
```

---

# Backend Services Overview

| Service | Purpose |
|---|---|
| signedurl | Generates secure upload URLs for ESP32 uploads |
| autotranscribe | Processes uploaded WAV files and generates transcripts |

---

# Recommended Validation

Before deployment:

1. Verify all backend files exist
2. Verify Node.js is installed
3. Verify npm is installed

Check versions:

```bash
node --version
npm --version
```

---

# Install Node.js (If Necessary)

Official download page:

- :contentReference[oaicite:2]{index=2}

Recommended:
- Use the latest LTS release

---

# Stage 5 — Deploy Signed URL Backend

This backend service:

* authenticates upload requests,
* generates signed upload URLs,
* and initializes upload sessions.

---

# Navigate to Backend Directory

```bash id="zqrf92"
cd backend/signedurl
```

---

# Install Dependencies

```bash id="7fgrho"
npm install
```

---

# Recommended Environment Variables

Create:

```text id="9z7z8m"
.env
```

Example:

```env id="qewn8r"
BUCKET_NAME=audionote-recordings
GOOGLE_CLOUD_PROJECT=your-project-id
```

---

# Deploy to Cloud Run

Example deployment command:

```bash id="m1j4hj"
gcloud run deploy signedurl-service \
  --source . \
  --region us-central1 \ 
  --allow-unauthenticated
```

For builders within Nigeria, the nearest region server is in "europe-west1". Replace the "us-central1" with this.

---

# Cloud Run Documentation

* [Cloud Run Deployment Guide](https://cloud.google.com/run/docs/deploying-source-code?utm_source=chatgpt.com)

---

# Validation Checkpoint

Expected result:

* Cloud Run deployment URL generated

Example:

```text id="0s0icn"
https://signedurl-service-xxxxx.run.app
```

Test endpoint accessibility in browser or Postman.

---

# Stage 6 — Configure ESP32 Upload Endpoint

Update firmware configuration:

```cpp id="8jm1j0"
const char *backendUrl = "https://your-cloud-run-url.run.app";  // Your GCF endpoint
```

Re-upload firmware after modification.

---

# Stage 7 — Deploy Auto-Transcription Backend

The auto-transcription backend:

* detects uploaded audio,
* calls Speech-to-Text,
* processes transcripts,
* and prepares archival outputs.

---

# Navigate to Backend Directory

```bash id="6e5g2s"
cd backend/autotranscribe
```

---

# Install Dependencies

```bash id="k9xwob"
npm install
```

---

# Recommended Environment Variables

Example:

```env id="5snfow"
BUCKET_NAME=audionote-recordings
GOOGLE_CLOUD_PROJECT=your-project-id
```

---

# Deploy Service

```bash id="wyxjlwm"
gcloud run deploy autoTranscribeOnUpload \
  --source . \
  --region europe-west1 \
  --allow-unauthenticated
```

---

# Stage 8 — Configure Cloud Storage Trigger

The transcription backend should trigger automatically when a WAV file is uploaded.

Recommended trigger workflow:

```text id="iyvdrx"
Cloud Storage Upload
        ↓
Trigger Event
        ↓
Auto-Transcription Backend
```

---

# Eventarc / Trigger Documentation

* [Google Eventarc Documentation](https://cloud.google.com/eventarc/docs?utm_source=chatgpt.com)

---

# Stage 9 — Configure IAM Permissions

Proper IAM permissions are required for:

* Cloud Run,
* Storage access,
* Speech-to-Text access,
* and Drive integration.

---

# Recommended Service Account Permissions

| Role | Purpose |
| --- | --- |
| Storage Admin | Bucket access |
| Cloud Run Admin | Service management |
| Speech Client | STT access |
| Service Account User | Service execution  |

---

# IAM Documentation

* [Google Cloud IAM Documentation](https://cloud.google.com/iam/docs?utm_source=chatgpt.com)

---

# Stage 10 — Configure Speech-to-Text Processing

Audionote currently uses:

* post-recording batch transcription.

This means:

* the ESP32 uploads WAV recordings,
* then backend services process them asynchronously.

---

# Speech-to-Text Documentation

* [Google Speech-to-Text Documentation](https://cloud.google.com/speech-to-text/docs?utm_source=chatgpt.com)

---

# Recommended Audio Settings

| Parameter | Recommendation |
| --- | --- |
| Encoding | LINEAR16 |
| Format | WAV |
| Channels | Mono |
| Sample Rate | Match firmware configuration |

---

# Validation Checkpoint

Expected results:

| Validation Item | Expected Result |
| --- | --- |
| Upload succeeds | Successful |
| WAV stored in bucket | Successful |
| Transcription starts | Successful |
| Transcript generated | Successful |

---

# Important Engineering Note — Backend Integration & Debugging

The backend deployment and integration stage is the most technically demanding part of the Audionote system.

This stage combines multiple distributed systems simultaneously:

- embedded firmware,
- cloud infrastructure,
- event-driven backend triggers,
- asynchronous uploads,
- authentication systems,
- transcription APIs,
- and storage automation.

Because of this, it is completely normal to encounter:
- deployment errors,
- permission issues,
- upload failures,
- API configuration problems,
- trigger failures,
- authentication mismatches,
- or inconsistent backend behavior during development.

---

# Expect Significant Debugging

Unlike simple frontend or static software projects, Audionote is a full-stack embedded cloud system.

A single issue may originate from:
- firmware configuration,
- incorrect backend endpoints,
- bucket permissions,
- IAM roles,
- malformed uploads,
- transcription configuration,
- or trigger automation.

Debugging often requires:
- reading logs carefully,
- testing incrementally,
- isolating subsystems,
- and validating one stage at a time.

Patience and perseverance are extremely important during this stage.

---

# Recommended Development Strategy

Avoid changing multiple systems simultaneously.

Instead:

```text
Validate Firmware
        ↓
Validate Upload
        ↓
Validate Bucket Storage
        ↓
Validate Trigger Activation
        ↓
Validate Transcription
        ↓
Validate Shared Drive Integration
```

This makes debugging significantly easier.

---

# Reading Backend Logs

Cloud logs are one of the most important debugging tools during development.

Useful command:

```bash
gcloud functions logs read autoTranscribeOnUpload --gen2 --region=europe-west1
```

This can help diagnose:
- trigger failures,
- backend crashes,
- permission problems,
- transcription issues,
- and deployment errors.

---

# Google Cloud Logging Console

You can also inspect logs visually through the Google Cloud console:

* [Google Cloud Logging Console](https://console.cloud.google.com/logs?utm_source=chatgpt.com)

Useful for:
- real-time debugging,
- filtering backend events,
- and monitoring deployment behavior.

---

# Using Built-In Gemini AI Chat side panel

Google Cloud Platform (GCP) console includes built-in AI assistance which can help explain:
- deployment errors,
- terminal issues,
- IAM problems,
- Node.js errors,
- and Cloud Run failures.

Shortcut:

```text
Alt + G
```

This opens the integrated AI assistance panel.

This can be surprisingly useful for:
- interpreting logs,
- understanding error messages,
- and troubleshooting deployment problems during development.

---

# Important Mindset During Development

Large engineering systems rarely work perfectly on the first deployment.

The debugging process itself is part of the engineering experience.

Working through:
- infrastructure problems,
- firmware integration issues,
- asynchronous backend behavior,
- and cloud deployment challenges

develops valuable real-world systems engineering skills.

---

# Recommended Best Practices

| Best Practice | Why It Helps |
|---|---|
| Test incrementally | Easier debugging |
| Read logs frequently | Faster issue isolation |
| Validate one subsystem at a time | Prevents cascading failures |
| Use small test recordings initially | Reduces upload complexity |
| Keep backup firmware versions | Easier rollback |
| Document working configurations | Prevents regression |

---

# Engineering Reality

Backend-cloud integration for embedded systems can sometimes take longer to debug than building the hardware itself.

This is normal.

Successfully integrating:
- firmware,
- storage systems,
- cloud infrastructure,
- event automation,
- and transcription pipelines

is already a strong demonstration of practical engineering capability.

---

# Common Backend Issues

| Problem | Possible Cause | Suggested Fix |
| --- | --- | --- |
| Upload rejected | Invalid signed URL | Verify backend endpoint |
| Cloud Run deployment fails | Billing disabled | Enable billing |
| STT fails | API not enabled | Enable Speech API |
| Trigger not firing | Incorrect Eventarc setup | Verify trigger configuration |
| Permission denied | IAM misconfiguration | Verify service account roles |
| Upload timeout | Large file/chunk size | Reduce upload chunk size |

---

# Backend Validation Checklist

| Validation Item | Expected Result |
| --- | --- |
| Cloud Run deployed | Successful |
| Signed URLs generated | Successful |
| Upload reaches bucket | Successful |
| WAV files stored | Successful |
| Transcription generated | Successful |
| Logs visible | Successful |

---

# Recommended Next Step

Once backend deployment and transcription processing are validated successfully, proceed to Shared Drive integration and automated archival setup.

Continue to:

→ [Shared Drive Setup Guide](shared-drive-integration.md)

Then:

→ [Final System Integration](../05-system-integration/full-system-integration.md)

---

# Additional Resources

## Cloud Run Documentation

* [Google Cloud Run Documentation](https://cloud.google.com/run/docs?utm_source=chatgpt.com)

## Cloud Storage Documentation

* [Google Cloud Storage Documentation](https://cloud.google.com/storage/docs?utm_source=chatgpt.com)

## Speech-to-Text Documentation

* [Google Speech-to-Text Documentation](https://cloud.google.com/speech-to-text/docs?utm_source=chatgpt.com)

## Google Drive API Documentation

* [Google Drive API Documentation](https://developers.google.com/drive?utm_source=chatgpt.com)

## Eventarc Documentation

* [Google Eventarc Documentation](https://cloud.google.com/eventarc/docs?utm_source=chatgpt.com)

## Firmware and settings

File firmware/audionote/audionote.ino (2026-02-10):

#include <Arduino.h>
#include <ArduinoJson.h>
#include <WiFi.h>
#include <WiFiClientSecure.h>
#include <HTTPClient.h>
#include <FS.h>
#include <SD.h>
#include <SPI.h>
#include "driver/i2s.h"

// ------------------ CONFIG ------------------
#define I2S_WS 25   // L/R clock
#define I2S_SD 33   // Serial data
#define I2S_SCK 32  // Bit clock
#define I2S_PORT I2S_NUM_0

// SD Card Pinouts
#define SD_CS 5  // SD card CS
#define SCK 18
#define MISO 19
#define MOSI 23

#define BUTTON_PIN 14  // Push button

const char *ssid = "YOUR_SSID";
const char *password = "YOUR_WIFI_PASSOWRD";
const char *backendUrl = "YOUR_BACKEND_URL";  // Your GCF endpoint

// ------------------ COURSE INFO ------------------
const char *COURSE_CODE = "COURSE_CODE"; //eg. EEE313, ECE102, etc.
const int COURSE_LEVEL = "COURSE_LEVEL";  // eg. 100, 200, 300, ... // Remove the quotes because it would be a number.

const char *DEVICE_ID = "DEVICE_ID"; //eg. esp32a1; you can create an ID for each device.

// Audio config
#define SAMPLE_RATE 16000
#define BITS_PER_SAMPLE 16
#define I2S_READ_LEN 1024
#define WAV_HEADER_SIZE 44
#define CHANNELS 1

// Globals
File recordingFile;
String currentFilename = "";
bool isRecording = false;
unsigned long silenceStart = 0;
bool sdReady = false;

// ------------------ I2S SETUP ------------------
void setupI2S() {
  i2s_config_t i2s_config = {
    .mode = (i2s_mode_t)(I2S_MODE_MASTER | I2S_MODE_RX),
    .sample_rate = SAMPLE_RATE,
    .bits_per_sample = I2S_BITS_PER_SAMPLE_32BIT,
    .channel_format = I2S_CHANNEL_FMT_ONLY_LEFT,
    .communication_format = (i2s_comm_format_t)(I2S_COMM_FORMAT_STAND_I2S),
    .intr_alloc_flags = ESP_INTR_FLAG_LEVEL1,
    .dma_buf_count = 8,
    .dma_buf_len = 1024
  };
  i2s_pin_config_t pin_config = {
    .bck_io_num = I2S_SCK,
    .ws_io_num = I2S_WS,
    .data_out_num = -1,
    .data_in_num = I2S_SD
  };
  i2s_driver_install(I2S_NUM_0, &i2s_config, 0, NULL);
  i2s_set_pin(I2S_NUM_0, &pin_config);
}

// ------------------ WAV HEADER ------------------
void writeWavHeader(File file, int sampleRate, int bitsPerSample, int totalSamples) {
  byte header[44];
  int byteRate = sampleRate * bitsPerSample / 8;
  int dataSize = totalSamples * bitsPerSample / 8;

  memcpy(header, "RIFF", 4);
  *((int *)&header[4]) = dataSize + 36;
  memcpy(&header[8], "WAVEfmt ", 8);
  *((int *)&header[16]) = 16;
  *((short *)&header[20]) = 1;
  *((short *)&header[22]) = 1;
  *((int *)&header[24]) = sampleRate;
  *((int *)&header[28]) = byteRate;
  *((short *)&header[32]) = bitsPerSample / 8;
  *((short *)&header[34]) = bitsPerSample;
  memcpy(&header[36], "data", 4);
  *((int *)&header[40]) = dataSize;
  file.write(header, 44);
}

void finalizeWav(File file) {
  file.seek(4);
  uint32_t fileSize = file.size() - 8;
  file.write((byte *)&fileSize, 4);
  file.seek(40);
  uint32_t dataSize = file.size() - 44;
  file.write((byte *)&dataSize, 4);
}

// ------------------ FILENAME ------------------
String nextFilename() {
  int index = 0;
  String filename;
  do {
    filename = "/LEC" + String(index) + ".wav";
    index++;
  } while (SD.exists(filename));
  return filename;
}

// ------------------ UPLOAD ------------------

// helper: URL-encode a filename (simple)
String urlEncode(const String &str) {
  String encoded = "";
  char c;
  char buf[4];
  for (size_t i = 0; i < str.length(); ++i) {
    c = str[i];
    if (isalnum(c) || c == '-' || c == '_' || c == '.' || c == '~') {
      encoded += c;
    } else if (c == ' ') {
      encoded += '+';
    } else {
      sprintf(buf, "%%%02X", (uint8_t)c);
      encoded += buf;
    }
  }
  return encoded;
}

// ---------- Persist basic upload state on SD (simple JSON) ----------
bool saveUploadStateToSD(const String &sessionUrl, const String &recordingId, const String &objectPath) {
  StaticJsonDocument<512> doc;
  doc["sessionUrl"] = sessionUrl;
  doc["recordingId"] = recordingId;
  doc["objectPath"] = objectPath;

  File f = SD.open("/upload_state.json", FILE_WRITE);
  if (!f) return false;

  serializeJson(doc, f);
  f.close();
  return true;
}

bool loadUploadStateFromSD(String &sessionUrl, String &recordingId, String &objectPath) {
  if (!SD.exists("/upload_state.json")) return false;

  File f = SD.open("/upload_state.json", FILE_READ);
  if (!f) return false;

  StaticJsonDocument<512> doc;
  DeserializationError err = deserializeJson(doc, f);
  f.close();
  if (err) return false;

  sessionUrl = String(doc["sessionUrl"] | "");
  recordingId = String(doc["recordingId"] | "");
  objectPath = String(doc["objectPath"] | "");

  return sessionUrl.length() > 0;
}

void clearUploadStateOnSD() {
  if (SD.exists("/upload_state.json")) SD.remove("/upload_state.json");
}

// ---------- Get signed URL + start resumable session ----------
String getsignedUrlResumable(const String &filename, String &outRecordingId, String &outObjectPath) {
  if (WiFi.status() != WL_CONNECTED) {
    Serial.println("WiFi not connected");
    return "";
  }

  // Build request URL; prefer POST with JSON body
  String reqUrl = String(backendUrl) + "/getsignedUrl";  // your Cloud Run route

  WiFiClientSecure clientHTTPS;
  clientHTTPS.setInsecure();
  HTTPClient http;

  http.begin(clientHTTPS, reqUrl);
  http.addHeader("Content-Type", "application/json");

  // request JSON {"filename":"...","resumable":true}
  StaticJsonDocument<256> doc;
  doc["filename"] = filename;
  doc["deviceId"] = DEVICE_ID;
  doc["resumable"] = true;
  doc["course_code"] = COURSE_CODE;
  doc["level"] = COURSE_LEVEL;


  String body;
  serializeJson(doc, body);

  // Debug print to confirm that course info is being sent
  Serial.println("📤 Upload metadata:");
  Serial.printf("  Course: %s\n", COURSE_CODE);
  Serial.printf("  Level: %d\n", COURSE_LEVEL);


  int code = http.POST(body);
  if (code != HTTP_CODE_OK && code != HTTP_CODE_CREATED) {
    Serial.printf("getsignedUrlResumable POST failed: %d\n", code);
    Serial.println("Response:");
    Serial.println(http.getString());
    http.end();
    return "";
  }

  String payload = http.getString();
  http.end();

  Serial.println("--- Backend JSON Response ---");
  Serial.println(payload);
  Serial.println("-----------------------------");

  // Parse JSON
  StaticJsonDocument<2048> resp;
  DeserializationError err = deserializeJson(resp, payload);
  if (err) {
    Serial.print("JSON parse failed: ");
    Serial.println(err.c_str());
    Serial.println("Payload:");
    Serial.println(payload);
    return "";
  }

  // Extract the ACTUAL resumable session URL
  String sessionUrl = "";
  if (resp.containsKey("resumableUrl")) sessionUrl = resp["resumableUrl"].as<String>();
  else if (resp.containsKey("uploadUrl")) sessionUrl = resp["uploadUrl"].as<String>();

  if (sessionUrl.length() == 0) {
    Serial.println("ERROR: Backend did not return a resumable session URL.");
    return "";
  }

  // Extract metadata from backend
  outRecordingId = resp["recordingId"] | "";
  outObjectPath = resp["objectPath"] | "";

  Serial.println("Resumable Session URL (ready to upload):");
  Serial.println(sessionUrl);
  Serial.println("Recording ID: " + outRecordingId);
  Serial.println("Object Path: " + outObjectPath);

  // Save state for resuming later
  saveUploadStateToSD(sessionUrl, outRecordingId, outObjectPath);

  return sessionUrl;  // RETURN THE READY-TO-USE resumable URL
}

// ---------- splitUrl() ----------
void splitUrlPreserveQuery(const String &url, String &host, String &path) {
  int idx1 = url.indexOf("://");
  int idx2 = url.indexOf('/', idx1 + 3);

  host = url.substring(idx1 + 3, idx2);

  // MUST keep everything after '/'
  path = url.substring(idx2);
}

#define GCS_CHUNK_SIZE 262144  // 256 KB (MANDATORY for GCS)
#define STREAM_BUF_SIZE 4096   // ESP32-safe


bool uploadFileInChunks(const String &sessionUrl, const String &sdFilePath) {
  File f = SD.open(sdFilePath, FILE_READ);
  if (!f) {
    Serial.println("❌ Failed to open SD file");
    return false;
  }

  uint64_t totalSize = f.size();
  uint64_t offset = 0;

  Serial.printf("📦 File size: %llu bytes\n", totalSize);
  Serial.printf("🧠 Free heap (start): %u\n", ESP.getFreeHeap());

  // Use heap buffer to avoid stack overflow
  uint8_t *buffer = (uint8_t *)malloc(STREAM_BUF_SIZE);
  if (!buffer) {
    Serial.println("❌ Failed to allocate heap buffer");
    f.close();
    return false;
  }

  String host, path;
  splitUrlPreserveQuery(sessionUrl, host, path);
  if (host.length() == 0 || path.length() == 0) {
    Serial.println("❌ Invalid resumable URL (host/path empty)");
    free(buffer);
    f.close();
    return false;
  }

  while (offset < totalSize) {
    uint64_t remaining = totalSize - offset;
    bool isFinalChunk = remaining <= GCS_CHUNK_SIZE;
    uint64_t chunkSize = isFinalChunk ? remaining : GCS_CHUNK_SIZE;

    Serial.printf("⬆ Uploading chunk: offset=%llu size=%llu\n", offset, chunkSize);

    WiFiClientSecure client;
    client.setInsecure();

    if (!client.connect(host.c_str(), 443)) {
      Serial.println("❌ TLS connect failed");
      free(buffer);
      f.close();
      return false;
    }

    // ---- HTTP headers ----
    client.printf("PUT %s HTTP/1.1\r\n", path.c_str());
    client.printf("Host: %s\r\n", host.c_str());
    client.print("Content-Type: application/octet-stream\r\n");
    client.printf("Content-Length: %llu\r\n", chunkSize);
    client.printf("Content-Range: bytes %llu-%llu/%llu\r\n", offset, offset + chunkSize - 1, totalSize);
    client.print("Connection: close\r\n\r\n");

    // ---- Stream body in small buffer blocks ----
    uint64_t sent = 0;
    while (sent < chunkSize) {
      size_t toRead = min((uint64_t)STREAM_BUF_SIZE, chunkSize - sent);
      size_t r = f.read(buffer, toRead);
      if (r == 0) {
        Serial.println("❌ SD read error");
        client.stop();
        free(buffer);
        f.close();
        return false;
      }
      client.write(buffer, r);
      sent += r;
      yield();  // let ESP32 background tasks run
    }

    // ---- Wait for response ----
    unsigned long start = millis();
    while (!client.available()) {
      if (millis() - start > 15000) {
        Serial.println("❌ Server timeout");
        client.stop();
        free(buffer);
        f.close();
        return false;
      }
      delay(1);
    }

    String statusLine = client.readStringUntil('\n');
    statusLine.trim();
    Serial.println("⬅ " + statusLine);

    if (!statusLine.startsWith("HTTP/")) {
      Serial.println("❌ Invalid HTTP response");
      client.stop();
      free(buffer);
      f.close();
      return false;
    }

    int code = statusLine.substring(9, 12).toInt();
    String rangeHeader = "";

    while (client.connected() || client.available()) {
      if (!client.available()) {
        delay(1);
        continue;
      }
      String line = client.readStringUntil('\n');
      line.trim();
      if (line.length() == 0) break;
      if (line.startsWith("Range:")) rangeHeader = line;
    }

    client.stop();

    if (code == 200 || code == 201) {
      Serial.println("✅ Upload complete");
      break;
    } else if (code == 308) {
      if (rangeHeader.length()) {
        uint64_t last = atoll(rangeHeader.substring(rangeHeader.indexOf('-') + 1).c_str());
        offset = last + 1;
        f.seek(offset);
      } else {
        offset += chunkSize;
        f.seek(offset);
      }
    } else {
      Serial.printf("❌ Unexpected HTTP %d\n", code);
      free(buffer);
      f.close();
      return false;
    }
  }

  free(buffer);
  f.close();
  Serial.printf("🧠 Free heap (end): %u\n", ESP.getFreeHeap());
  return true;
}


// ---------------- SD Check ----------------
bool checkSD() {
  if (!SD.begin(SD_CS)) {
    if (sdReady) {
      Serial.println("SD card removed!");
      sdReady = false;
      if (isRecording) stopRecording();
    }
    return false;
  }
  if (!sdReady) {
    Serial.println("SD card ready.");
    sdReady = true;
  }
  return true;
}

// Print in smaller chunks
void printLongString(const String &str) {
  const int chunkSize = 128;
  for (size_t i = 0; i < str.length(); i += chunkSize) {
    Serial.println(str.substring(i, i + chunkSize));
    delay(1);  // give watchdog time
  }
}

// ---------------- Start/Stop ----------------
void startRecording() {
  if (!checkSD()) return;
  currentFilename = nextFilename();
  recordingFile = SD.open(currentFilename, FILE_WRITE);
  if (!recordingFile) {
    Serial.println("File open failed!");
    return; 
  }
  writeWavHeader(recordingFile, SAMPLE_RATE, BITS_PER_SAMPLE, CHANNELS);
  isRecording = true;
  silenceStart = millis();
  Serial.print("Recording started: ");
  Serial.println(currentFilename);
}

// ---------- stopRecording() updated flow ----------
void stopRecording() {
  if (!isRecording) return;

  finalizeWav(recordingFile);
  recordingFile.close();
  isRecording = false;
  Serial.println("Recording stopped & file saved: " + currentFilename);

  // If WiFi not available, skip upload for now
  if (WiFi.status() != WL_CONNECTED) {
    Serial.println("WiFi not connected; upload deferred.");
    return;
  }

  // Variables to be filled by the backend
  String recordingId, objectPath, sessionUrl;

  // 🔥 Get the short stable upload session URL
  sessionUrl = getsignedUrlResumable(
    currentFilename.substring(1),  // file name only, without '/'
    recordingId,
    objectPath);

  if (sessionUrl.length() == 0) {
    Serial.println("Could not get session URL; upload deferred.");
    return;
  }

  Serial.println("Uploading using sessionUrl (short, stable):");

  // --- Persist session to SD/NVS for future resume ----
  saveUploadStateToSD(sessionUrl, recordingId, objectPath);
  Serial.println("Session URL + recordingId saved to SD");

  delay(50);  // allow system tasks to run

  // 🔥 Upload using sessionUrl, not signedUrl
  bool ok = uploadFileInChunks(sessionUrl, currentFilename);

  if (ok) {
    Serial.println("Upload successful; clearing saved state");
    clearUploadStateOnSD();
  } else {
    Serial.println("Upload failed; state saved for resume.");
  }
}


// ------------------ SETUP ------------------
void setup() {
  Serial.begin(115200);
  pinMode(BUTTON_PIN, INPUT_PULLUP);

  WiFi.begin(ssid, password);
  Serial.print("Connecting to WiFi");
  while (WiFi.status() != WL_CONNECTED) {
    delay(500);
    Serial.print(".");
  }
  Serial.println("\nWiFi connected!");

  // if (!SD.begin(SD_CS)) {
  //   Serial.println("SD Card mount failed!");
  //   while (true)
  //     ;
  // }

  SPI.begin(SCK, MISO, MOSI, SD_CS);  // 🔑 critical for ESP32

  if (!checkSD()) {
    Serial.println("SD not ready at boot (will retry)");
  }


  setupI2S();
}

// ---------------- Loop ----------------
void loop() {
  static bool lastButtonState = HIGH;
  bool buttonState = digitalRead(BUTTON_PIN);

  if (lastButtonState == HIGH && buttonState == LOW) {
    if (!isRecording) startRecording();
    else stopRecording();
    delay(200);
  }
  lastButtonState = buttonState;

  if (isRecording && sdReady) {
    int32_t rawBuffer[512];
    size_t bytesRead;
    i2s_read(I2S_PORT, (char *)rawBuffer, sizeof(rawBuffer), &bytesRead, portMAX_DELAY);

    int samplesRead = bytesRead / 4;
    int16_t pcmBuffer[512];
    double sumSq = 0;
    for (int i = 0; i < samplesRead; i++) {
      int16_t sample = (int16_t)(rawBuffer[i] >> 13);
      pcmBuffer[i] = sample;
      sumSq += (double)sample * sample;
    }

    // float rms = sqrt(sumSq / samplesRead);
    // if (rms > 0) { float newGain = targetLevel / rms; gain = gain * (1.0 - agcSpeed) + newGain * agcSpeed; }

    // for (int i = 0; i < samplesRead; i++) {
    //     int32_t boosted = (int32_t)(pcmBuffer[i] * gain);
    //     if (boosted > 32767) boosted = 32767;
    //     if (boosted < -32768) boosted = -32768;
    //     pcmBuffer[i] = (int16_t)boosted;
    // }

    if (recordingFile) recordingFile.write((uint8_t *)pcmBuffer, samplesRead * 2);

    // if (isSilent(pcmBuffer, samplesRead)) {
    //     if (millis() - silenceStart > silenceLimit) {
    //         Serial.println("Auto-stopped (long silence).");
    //         stopRecording();
    //     }
    // } else silenceStart = millis();
  }

  checkSD();
}

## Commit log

2026-02-10 Replaced passowrds and sensitive info with text descriptions
    [audionote.ino]
2026-05-15 Create hardware and schematics folder
2026-05-15 Create bill-of-materials.md in 02 hardware folder
2026-05-15 Included the build stage table in readme
2026-05-16 Adding device image views
2026-05-16 Upload stage diagrams
2026-05-16 Uploading more build stage images
2026-05-16 Update README.md BOM
2026-05-16 Update bill-of-materials.md esp 32 url
2026-05-16 Update bill-of-materials.md image urls
2026-05-16 Update bill-of-materials.md images
2026-05-16 Update bill-of-materials.md. Fixed picture loading with a slash before "doc"
2026-05-16 Delete docs/08-assets/components/479uF capacitor.webp
    Incorrect naming
2026-05-16 Update bill-of-materials.md with the capacitor
2026-05-16 Update bill-of-materials.md "headers" error
2026-05-16 Update README.md with new README flow
2026-05-20 Update esp32-setup.md firmware
2026-05-20 Update assembly-guide.md inputting photos
2026-05-20 Update bill-of-materials.md include the microscale inmp441 product link
2026-05-20 Update bill-of-materials.md correct the microscale inmp441 product link
2026-05-20 Update bill-of-materials.md include for Nigerians cluase
2026-05-20 Update assembly-guide.md corrected image display markdown
2026-05-20 Create .gitkeep.md wiring folder
2026-05-20 Update assembly-guide.md with inmp441 wiring diagram\
2026-05-20 Update assembly-guide.md adjusted image sizes
2026-05-20 Update assembly-guide.md include dronebot hyperlinks
2026-05-20 Create .gitkeep for enclosure folder
2026-05-20 Update assembly-guide.md with inmp441 test src
2026-05-20 Update esp32-setup.md change the clone repo side
2026-05-20 Update esp32-setup.md with specific firmware download link
2026-05-20 Update bill-of-materials.md 470uf cap desc
2026-05-20 Update power-system.md tried inserting power wiring diagram
2026-05-20 Update power-system.md inserted the wiring diagram
2026-05-22 Update full-system-integration.md include enclosure pics
2026-05-23 Update assembly-guide.md update mic notes
2026-05-23 Update assembly-guide.md sd card notes
2026-05-23 Update full-system-integration.md 3d printable link
